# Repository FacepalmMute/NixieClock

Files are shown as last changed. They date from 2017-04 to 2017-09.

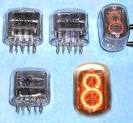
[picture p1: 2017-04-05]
doc/pic/ИН-12А-Picture.jpg

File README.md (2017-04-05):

# NixieClock
Combining Nixie tube technology with IoT
* Providing vintage style Nixie tube clock suitability for daily use.
* Building of a basis for testing and demonstrating IoT stuff using
  the [ESP8266](
  http://www.google.de/search?hl=de&source=hp&biw=&bih=&q=Mikrocontroller.net+ESP8266
  "Mikrocontroller.net ESP8266 - Google-Suche") in conjunction with
  the Arduino library.
* Open documentation allows designing of individual boxes, using of
  miscellaneous Nixie tubes, software and so forth within your own
  handicraft work.
  
# Firmware
The _firmware_ can be found in the Arduino folder. Compilation was
tested under Arduino.cc. You might use the libraries found in the
library folder. At least you will need the _NixieClock_
software. _DS1307RTC, Time-master_, and _Timezone-master_ are
available in their unimproved versions from Arduino and are assumed to
be yet part of your Arduino standard software installation. When using
the Arduino build system you can use any version you like without
problems.

When using Arduino Eclipse plugins you will get into trouble caused by
the redirection of the standard c-header file _Time.h_ that was done
in _Time-master._ This strange hijacking of the original _time.h_ is
responsible for wrecking the build process of the ESP8266 core
_arduino.ar._ So Eclipse users will likely use my modified versions of
_DS1307RTC, Time-master_, and _Timezone-master_ where I removed the
annoying redirection and detaching of standard headers.

Furthermore there are the two Arduino sketch folders _Nixie4_ and
_Nixie6._ _Nixie4_ is the firmware used by our 4 tube prototype;
_Nixie6_ is used by our 6 tube prototype.

## Prototype with 4 ИН-1 Nixie tubes
![Prototype ИН-1 Nixie clock](./pic/P1010273_s.jpg "4x ИН-1 tube
type")

This clock is an implementation with 4 ИН-1 Nixie tubes. 

## Prototype with 6 ИН-12А Nixie tubes
![Prototype ИН-12А Nixie clock](./pic/P1010278_s.jpg "6x ИН-12А tube
type")

# Hardware Description
![Beware of electric shock!](./pic/High_Voltage.jpg "Beware of
electric shock!")

**Beware of electric shock!**

**Beware of electrical safety hazards!**

**The Nixie tubes are fired at approx 200 Volt! There is definitely a
danger of hazardous voltage given! Never think of working on the Nixie
hardware when you are not educated in doing work with hazardous
voltages!**

The hardware description is given in EAGLE format and a PDF-file.

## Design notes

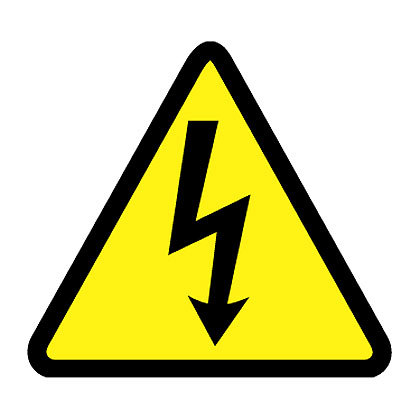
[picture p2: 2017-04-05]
pic/High_Voltage.jpg

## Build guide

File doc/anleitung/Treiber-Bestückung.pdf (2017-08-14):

## Nixie-Clock Treiber Bestückung

Die Treiberplatine liegt als EAGLE-file auf https://github.com/42nibbles/NixieClock/ vor. Sie wurde in EAGLE 7.0 erstellt und kann auch mit der freien Version geladen werden.
Diese Datei kann zu einem Platinenfertiger gesendet werden.
Wenn man sie selbst herstellen möchte, können die EAGLE-Files als PDF ausgedruckt und so für Herstellung der Filme eingesetzt werden.
Die Platine ist zweiseitig durchkontaktiert, bei selbst geätzten Platinen ist auf die korrekte Durchkontaktierung insbesondere an den IC-Sockeln zu achten. Für alle ICs sind Sockel einzusetzen, auf die korrekte Polung ist zu achten.
Der Programmierport JP1 ist als Buchse zu bestücken, der Stecker für die Erweiterung JP5 kann weggelassen werden.

Inbetriebnahme der Treiberplatine
Für die Inbetriebnahme der Treiberplatine empfiehlt es sich, zunächst die ICs für die Spannungsversorgung zu bestücken. Angefangen mit den 5V (LM2574) sollten die IC-Anschlüsse auf Spannung mit dem Multimeter überprüft werden.
Wenn die 5V-Spannung korrekt anliegt, wird der ESP8266-07 mit 3,3V versorgt, auch das sollte nachgemessen werden.
Die Hochspannung kann nicht direkt in Betrieb genommen werden, da sie über den MOSFET T10.1 (IRF9530) erst eingeschaltet wird.
An dem Stecker SV1 Pin 10 liegt die Hochspannung an erst an, wenn Source- und Drain-Anschluss von T10.1 miteinander verbunden werden.
Vorsicht, nicht mit dem HV-Schalter IRFB812P verwechseln!
VORSICHT!!!
Mit dem Voltmeter wird zwischen Masse und Pin10 des SV1 gemessen und die Spannung mit dem Potentiometer auf ca. 180V eingestellt.
Das sollte für nahezu alle Röhrentypen reichen.
Wenn die Röhren zu hell sind, kann über die Verringerung der Hochspannung die Leuchtstärke variiert werden.
Sind alle Spannungen korrekt eingestellt, können die Portextender-ICs, die RTC und die Treiber eingesetzt werden.
Für die Verbindung zwischen der Treiberplatine und der Anzeigeplatine sind Stecker und Buchsen vorgesehen.
Hier muss darauf geachtet werden, dass die Steckverbinder zueinander passen und die Pinbelegung stimmt, d.h jeweils PIN 1 auf PIN 1.
Durch verschiedene Kombinationen kann es hier zu Verdrehungen kommen, dann funktioniert nichts mehr!!!

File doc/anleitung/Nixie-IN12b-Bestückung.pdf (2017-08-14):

## Nixie-Clock IN12b Platinen-Bestückung

Auch hier liegen die EAGLE-Files auf https://github.com/42nibbles/NixieClock/.
Die Platine ist zweiseitig durchkontaktiert, allerdings sind hier keine Durchkontaktierungen an den Steckern und Röhren vorgesehen, lediglich an den Widerständen muss oben und unten gelötet werden.
Außerdem sind die Durchkontaktierungen vor den Steckern sorgfältig zu löten.

Die Röhren müssen in den Bohrungen vorsichtig justiert werden, da sie handgefertigt sind, sind die Ziffern der einzelnen Röhren nicht sauber justiert. Hier muss nach Sicht ausgeglichen werden. Die Röhren sollten dann mit Klebeband fixiert und angelötet werden.

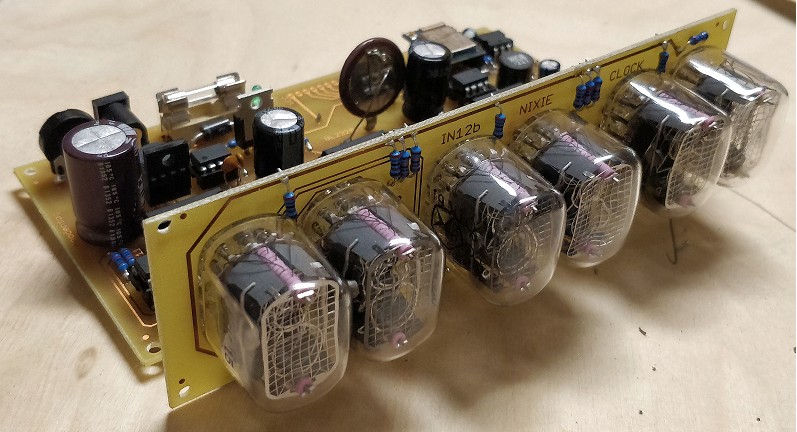
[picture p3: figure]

Quelle: Vincent Tummel

Wenn die Steckverbinder der Treiber- und der Röhrenplatine verlötet werden sollen, ist es ratsam, auch die beiden Platinen erst auszurichten (Rechter Winkel!) und zu fixieren und dann anzulöten.

Jetzt kann die Uhr, bzw der ESP8266 programmiert und die Uhr in Betrieb genommen werden.

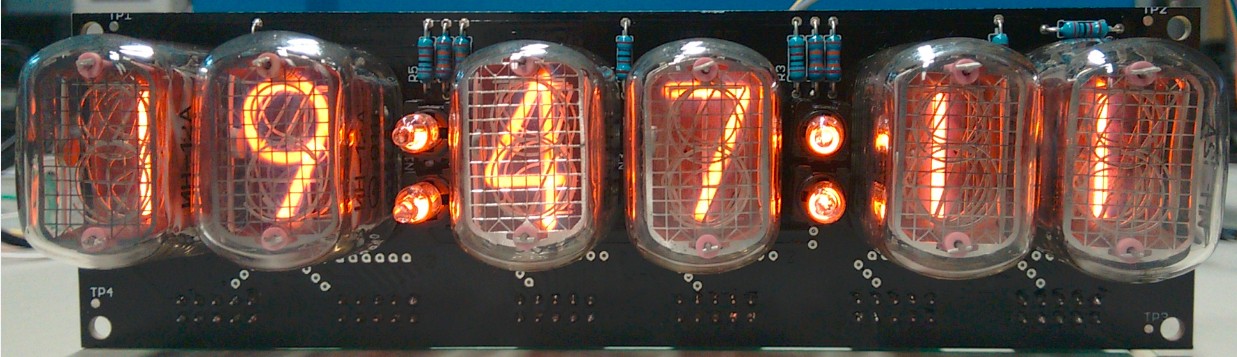
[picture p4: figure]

Quelle: Daniel Flaswinkel

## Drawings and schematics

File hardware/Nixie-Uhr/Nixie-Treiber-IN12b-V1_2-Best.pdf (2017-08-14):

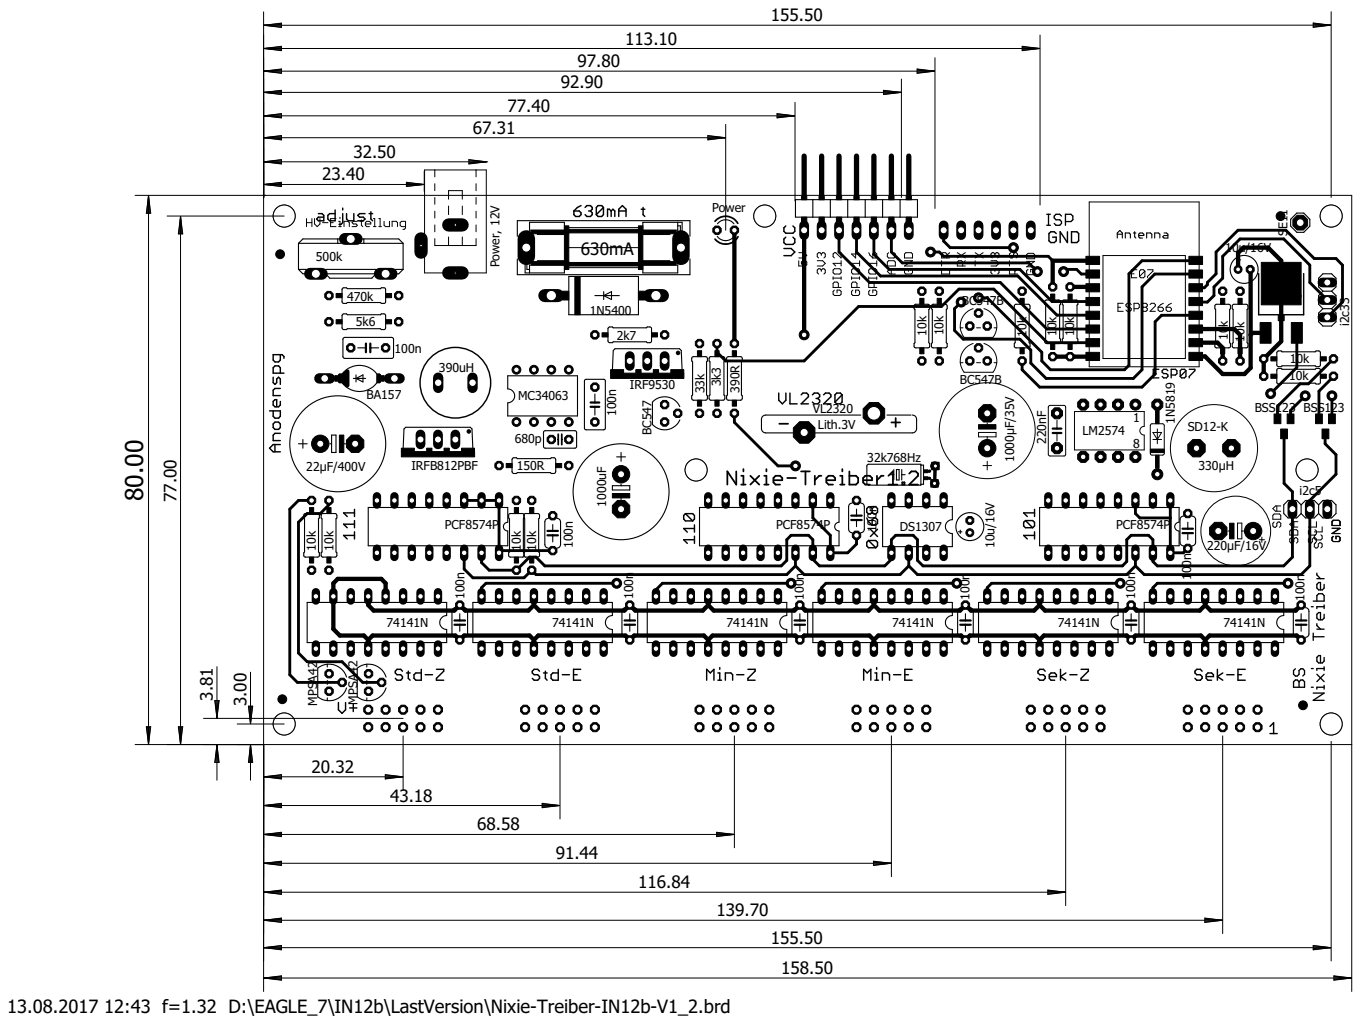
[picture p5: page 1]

13.08.2017 12:43 f=1.32 D:\EAGLE_7\IN12b\LastVersion\Nixie-Treiber-IN12b-V1_2.brd

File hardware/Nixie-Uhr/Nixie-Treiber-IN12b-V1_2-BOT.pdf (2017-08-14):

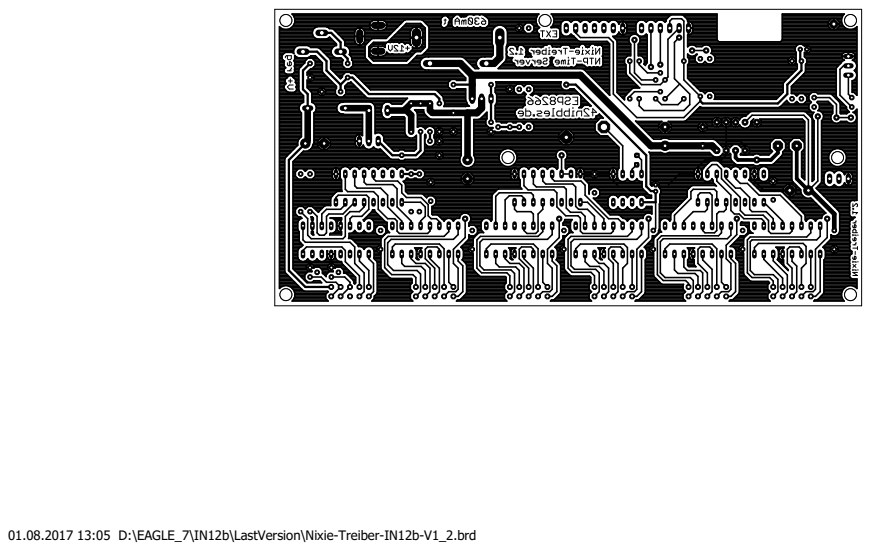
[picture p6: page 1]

01.08.2017 13:05 D:\EAGLE_7\IN12b\LastVersion\Nixie-Treiber-IN12b-V1_2.brd

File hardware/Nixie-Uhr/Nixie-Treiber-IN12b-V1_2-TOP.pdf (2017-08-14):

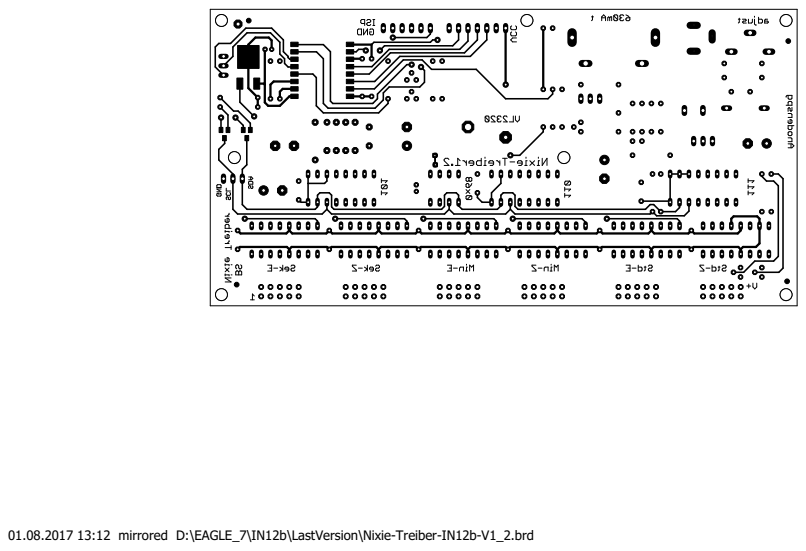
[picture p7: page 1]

01.08.2017 13:12 mirrored D:\EAGLE_7\IN12b\LastVersion\Nixie-Treiber-IN12b-V1_2.brd

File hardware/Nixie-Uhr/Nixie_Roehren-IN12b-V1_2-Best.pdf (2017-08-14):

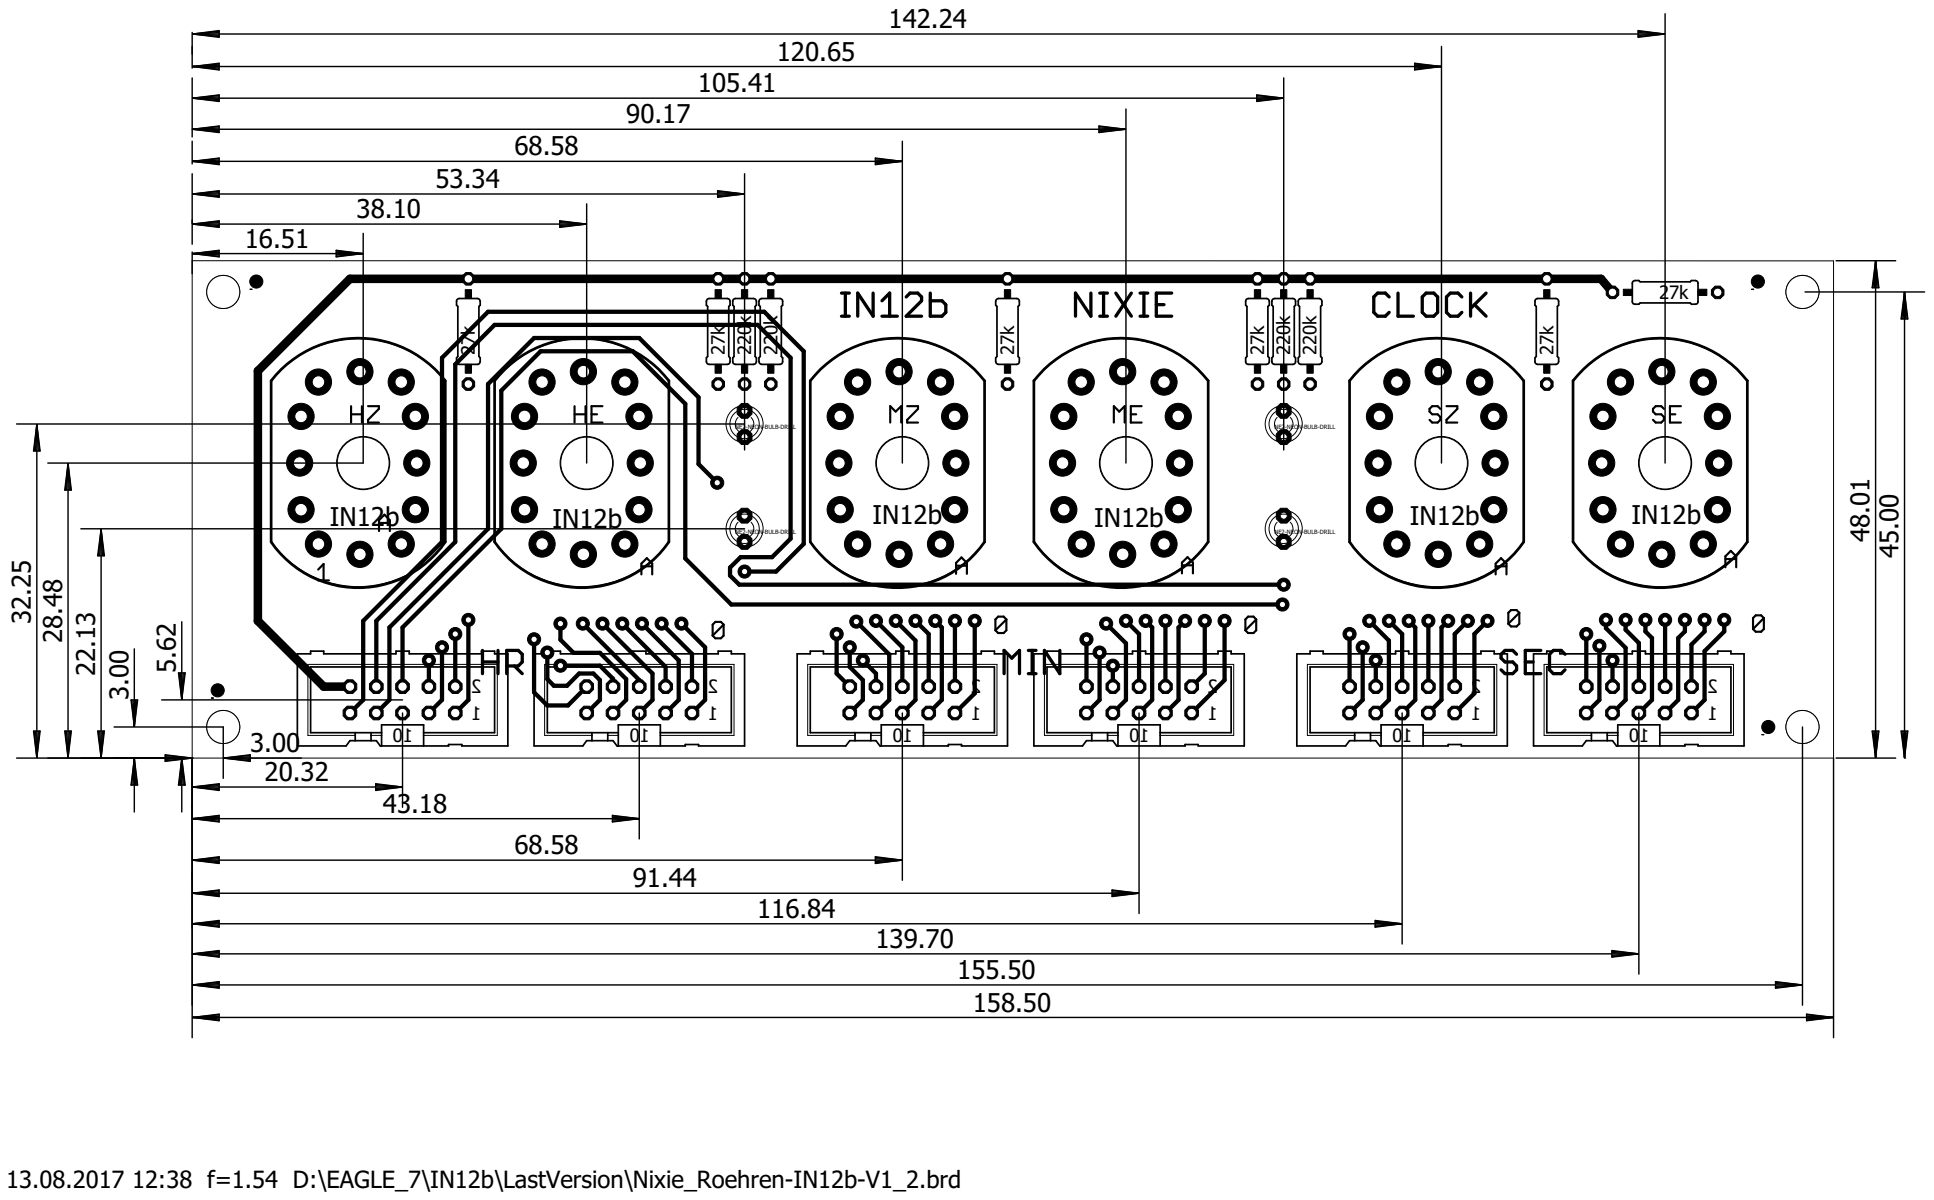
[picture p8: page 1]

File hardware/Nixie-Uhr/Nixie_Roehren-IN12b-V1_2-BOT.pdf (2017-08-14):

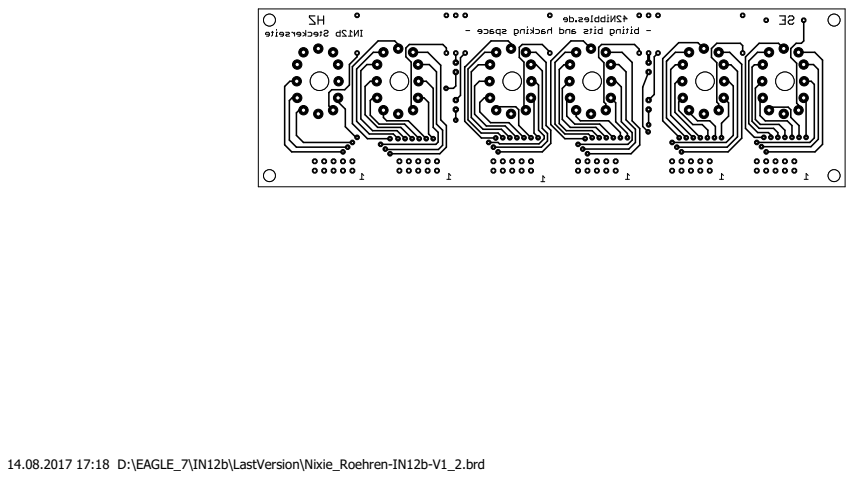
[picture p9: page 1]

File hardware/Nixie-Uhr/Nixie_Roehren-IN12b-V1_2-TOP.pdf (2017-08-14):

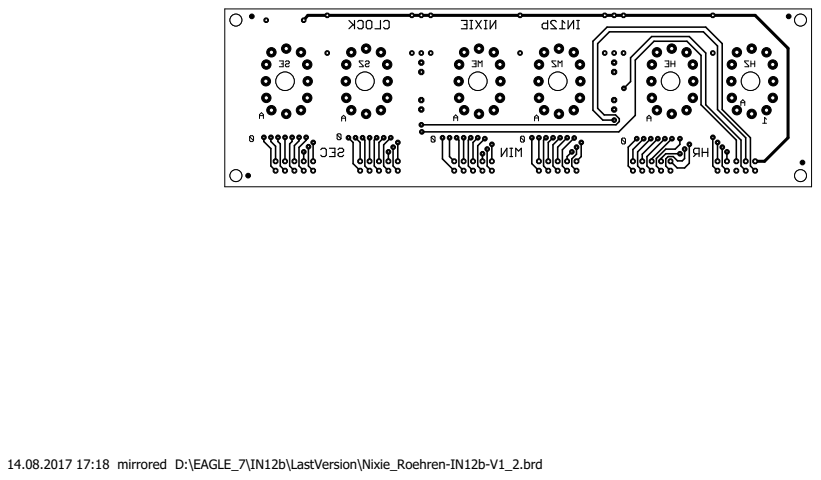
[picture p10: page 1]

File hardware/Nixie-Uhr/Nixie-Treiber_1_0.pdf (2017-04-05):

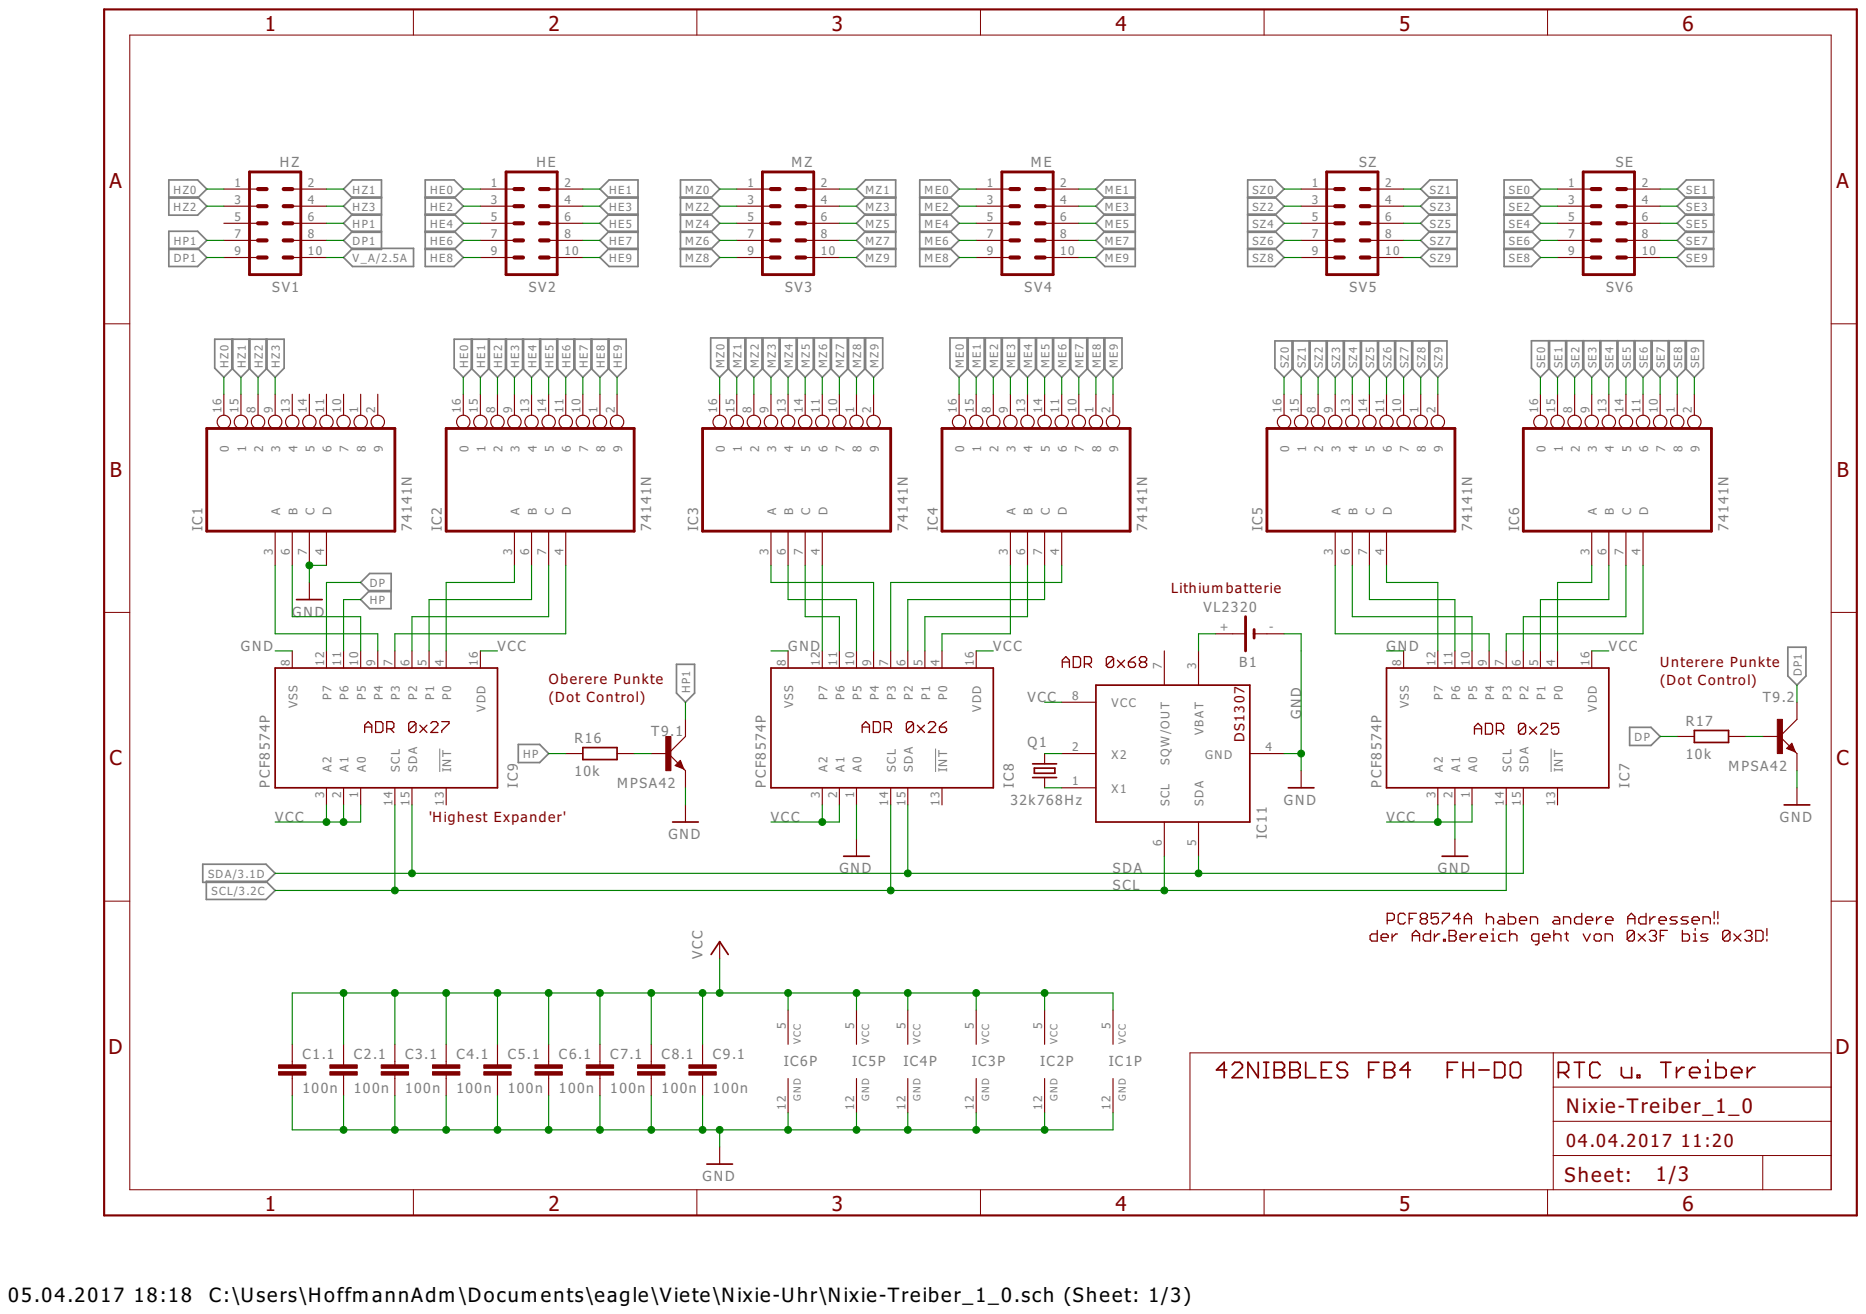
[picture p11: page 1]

05.04.2017 18:18 C:\Users\HoffmannAdm\Documents\eagle\Viete\Nixie-Uhr\Nixie-Treiber_1_0.sch (Sheet: 1/3)

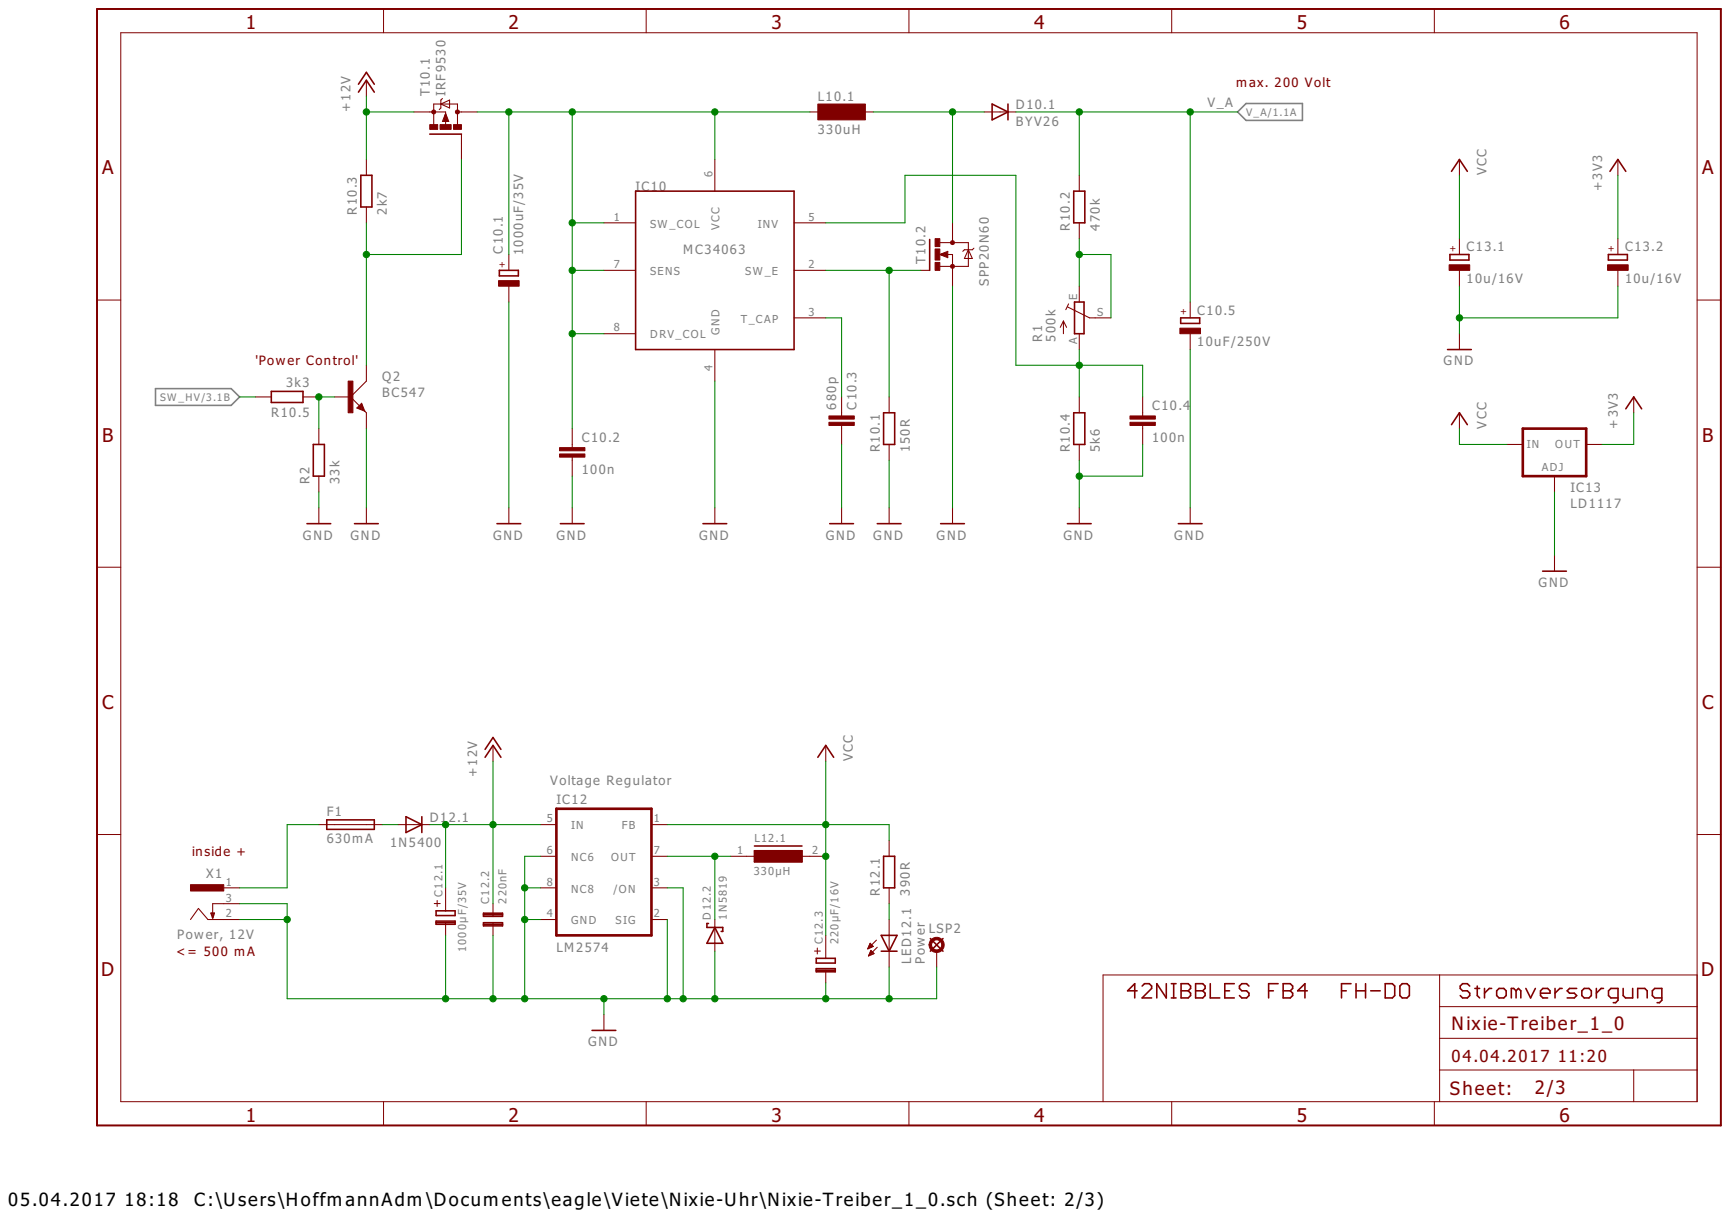
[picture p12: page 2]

05.04.2017 18:18 C:\Users\HoffmannAdm\Documents\eagle\Viete\Nixie-Uhr\Nixie-Treiber_1_0.sch (Sheet: 2/3)

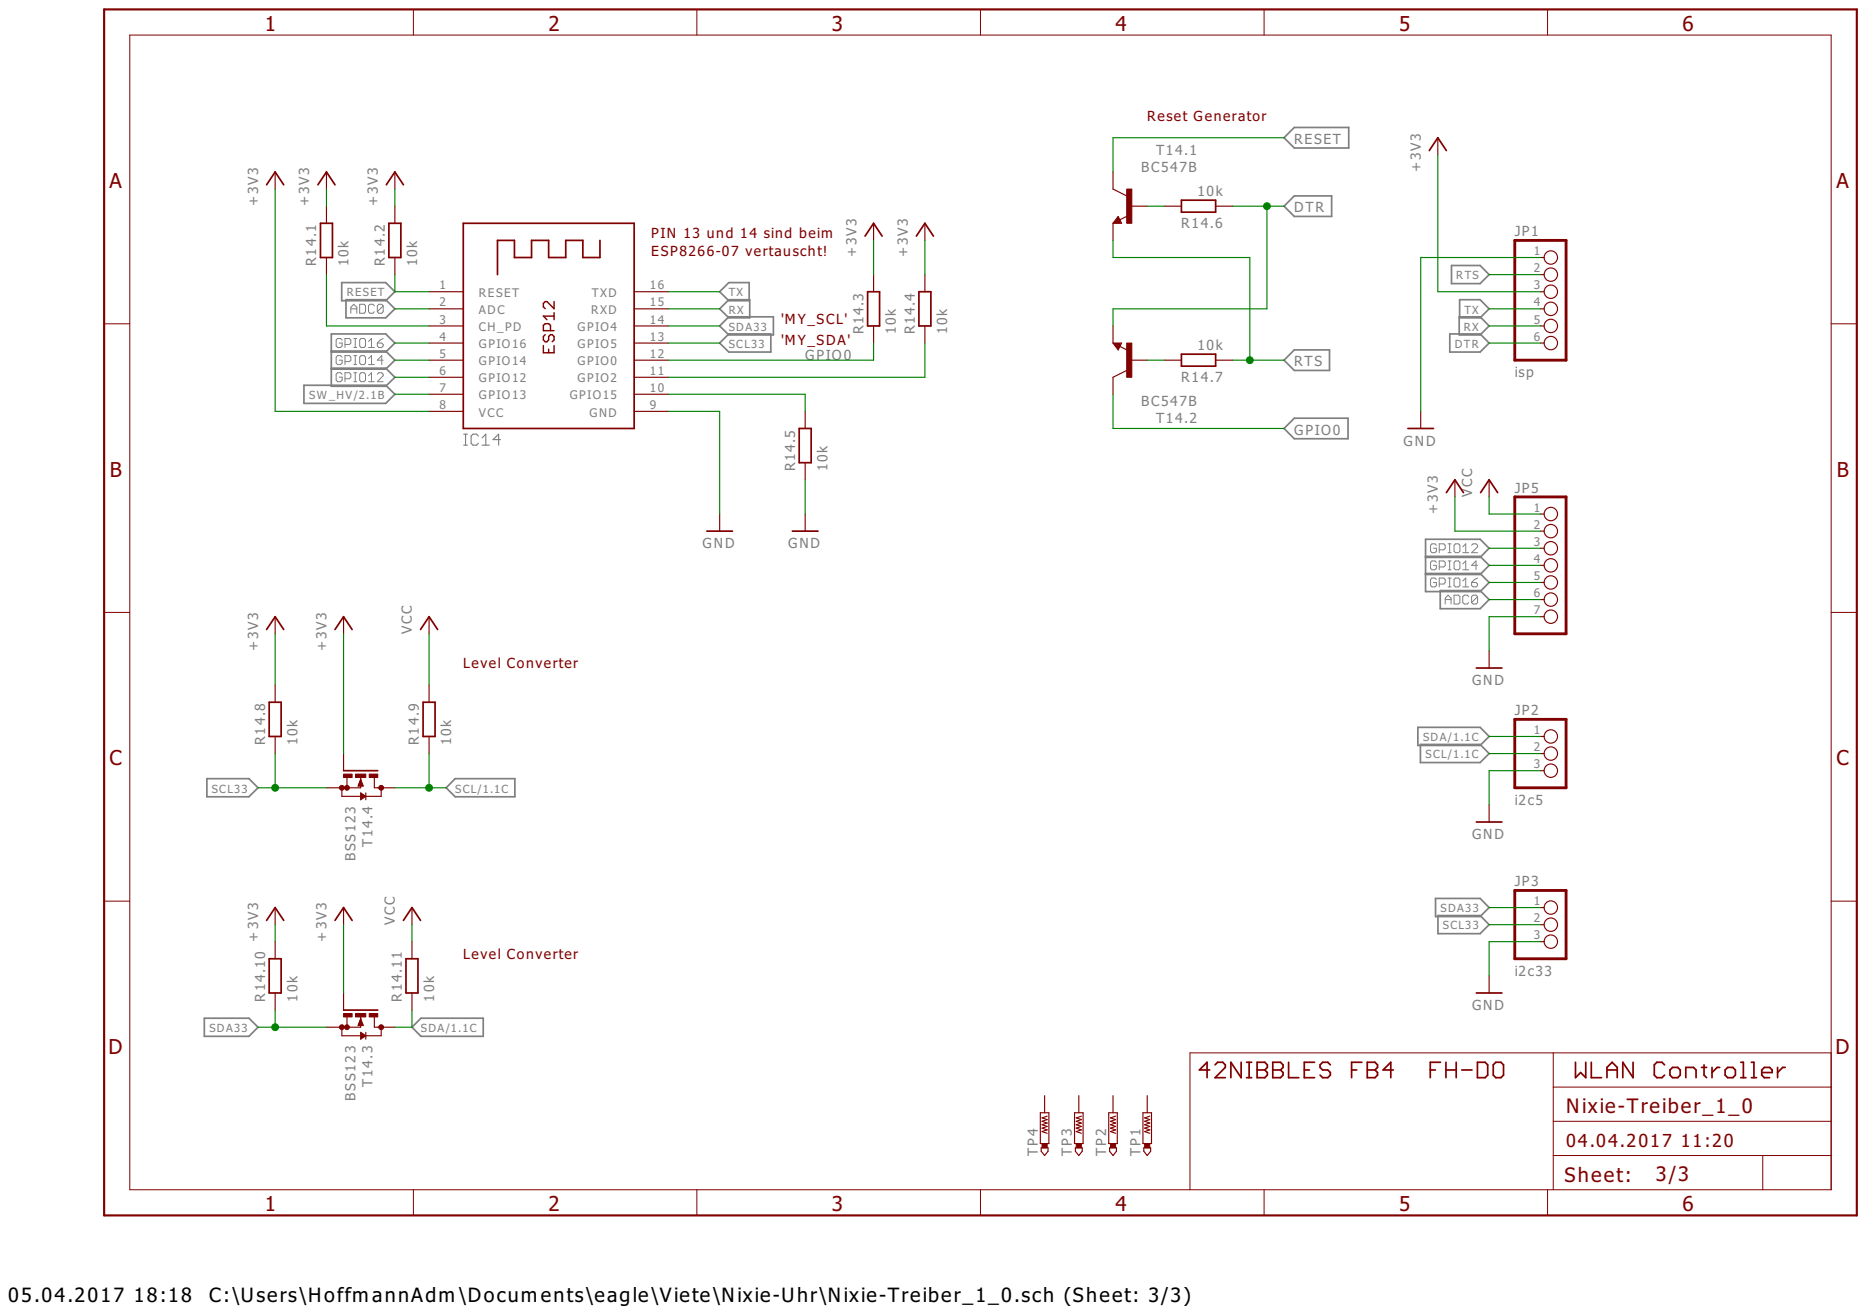
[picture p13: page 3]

PIN 13 und 14 sind beim
ESP8266-07 vertauscht!

05.04.2017 18:18 C:\Users\HoffmannAdm\Documents\eagle\Viete\Nixie-Uhr\Nixie-Treiber_1_0.sch (Sheet: 3/3)

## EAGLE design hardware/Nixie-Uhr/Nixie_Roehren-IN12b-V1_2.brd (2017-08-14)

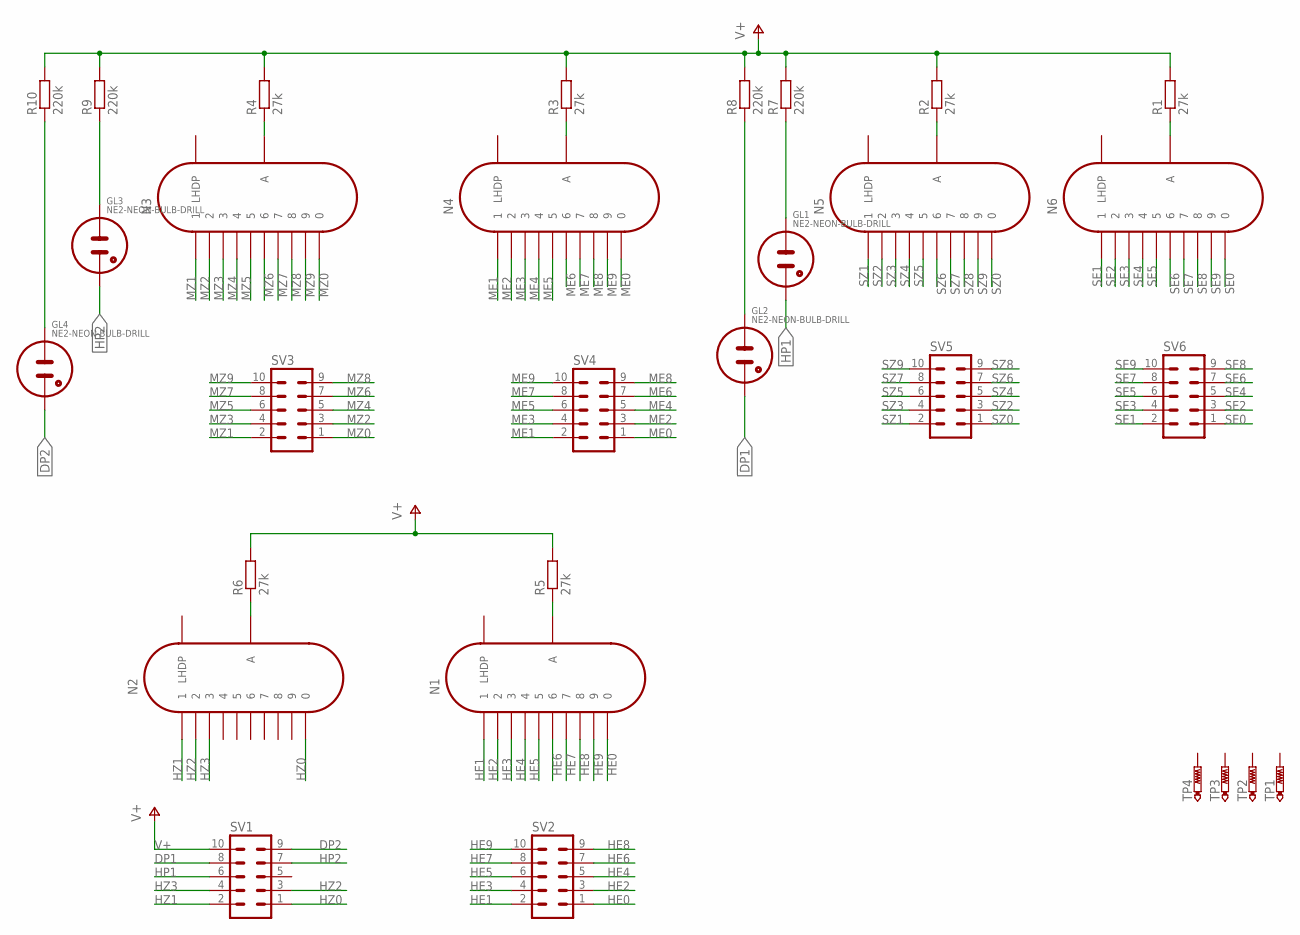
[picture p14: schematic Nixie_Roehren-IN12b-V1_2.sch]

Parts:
GL1, GL2, GL3, GL4: NE2-NEON-BULB-DRILL
N1, N2, N3, N4, N5, N6: IN-12B; IN-12
R1, R2, R3, R4, R5, R6: 27k; 0207/10
R7, R8, R9, R10: 220k; 0207/10
SV1, SV2, SV3, SV4, SV5, SV6: ML10
TP1, TP2, TP3, TP4: PTR1B1,27; B1,27

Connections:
DP1: GL2.2 (A1), SV1.8
DP2: GL4.2 (A1), SV1.9
HE0: N1.0, SV2.1
HE1: N1.1, SV2.2
HE2: N1.2, SV2.3
HE3: N1.3, SV2.4
HE4: N1.4, SV2.5
HE5: N1.5, SV2.6
HE6: N1.6, SV2.7
HE7: N1.7, SV2.8
HE8: N1.8, SV2.9
HE9: N1.9, SV2.10
HP1: GL1.2 (A1), SV1.6
HP2: GL3.2 (A1), SV1.7
HZ0: N2.0, SV1.1
HZ1: N2.1, SV1.2
HZ2: N2.2, SV1.3
HZ3: N2.3, SV1.4
ME0: N4.0, SV4.1
ME1: N4.1, SV4.2
ME2: N4.2, SV4.3
ME3: N4.3, SV4.4
ME4: N4.4, SV4.5
ME5: N4.5, SV4.6
ME6: N4.6, SV4.7
ME7: N4.7, SV4.8
ME8: N4.8, SV4.9
ME9: N4.9, SV4.10
MZ0: N3.0, SV3.1
MZ1: N3.1, SV3.2
MZ2: N3.2, SV3.3
MZ3: N3.3, SV3.4
MZ4: N3.4, SV3.5
MZ5: N3.5, SV3.6
MZ6: N3.6, SV3.7
MZ7: N3.7, SV3.8
MZ8: N3.8, SV3.9
MZ9: N3.9, SV3.10
unnamed: N2.A, R6.1
unnamed: N6.A, R1.1
unnamed: N5.A, R2.1
unnamed: N4.A, R3.1
unnamed: N3.A, R4.1
unnamed: GL2.1 (A), R8.1
unnamed: N1.A, R5.1
unnamed: GL1.1 (A), R7.1
unnamed: GL4.1 (A), R10.1
unnamed: GL3.1 (A), R9.1
SE0: N6.0, SV6.1
SE1: N6.1, SV6.2
SE2: N6.2, SV6.3
SE3: N6.3, SV6.4
SE4: N6.4, SV6.5
SE5: N6.5, SV6.6
SE6: N6.6, SV6.7
SE7: N6.7, SV6.8
SE8: N6.8, SV6.9
SE9: N6.9, SV6.10
SZ0: N5.0, SV5.1
SZ1: N5.1, SV5.2
SZ2: N5.2, SV5.3
SZ3: N5.3, SV5.4
SZ4: N5.4, SV5.5
SZ5: N5.5, SV5.6
SZ6: N5.6, SV5.7
SZ7: N5.7, SV5.8
SZ8: N5.8, SV5.9
SZ9: N5.9, SV5.10
V+: R1.2, R2.2, R3.2, R4.2, R5.2, R6.2, R7.2, R8.2, R9.2, R10.2, SV1.10

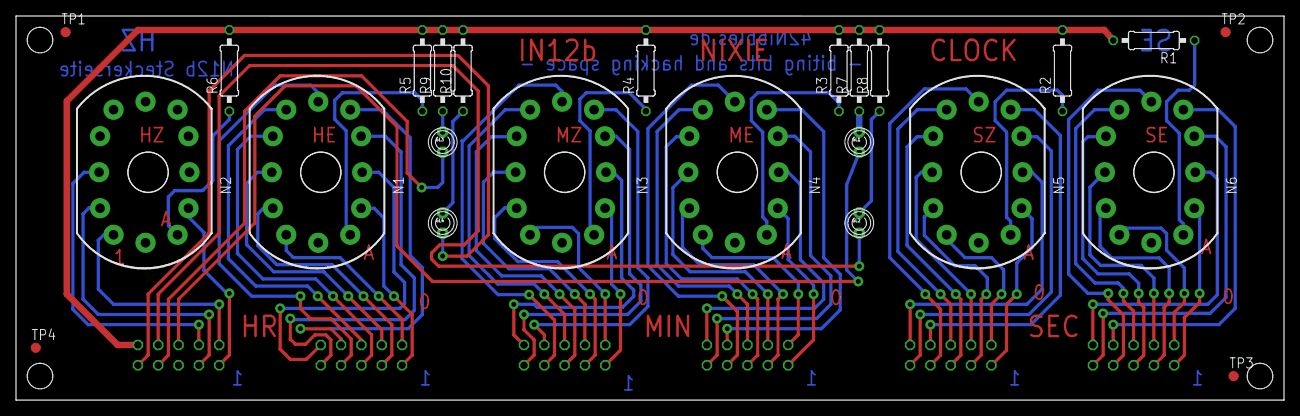
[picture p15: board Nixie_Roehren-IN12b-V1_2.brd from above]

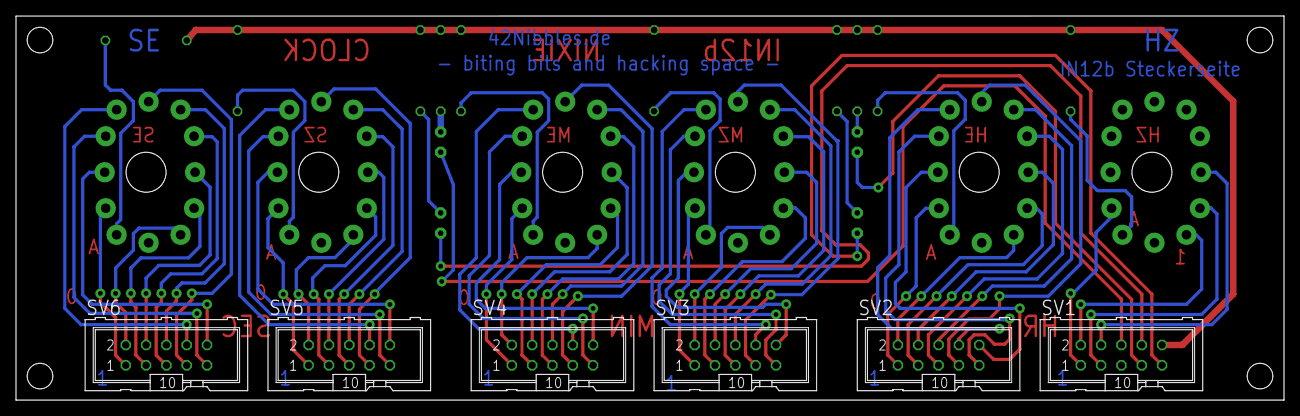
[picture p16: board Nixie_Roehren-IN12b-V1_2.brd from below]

Board: 2 copper layers, 158.5 x 48.0 mm, 30 parts (6 on the bottom side), 69 nets.

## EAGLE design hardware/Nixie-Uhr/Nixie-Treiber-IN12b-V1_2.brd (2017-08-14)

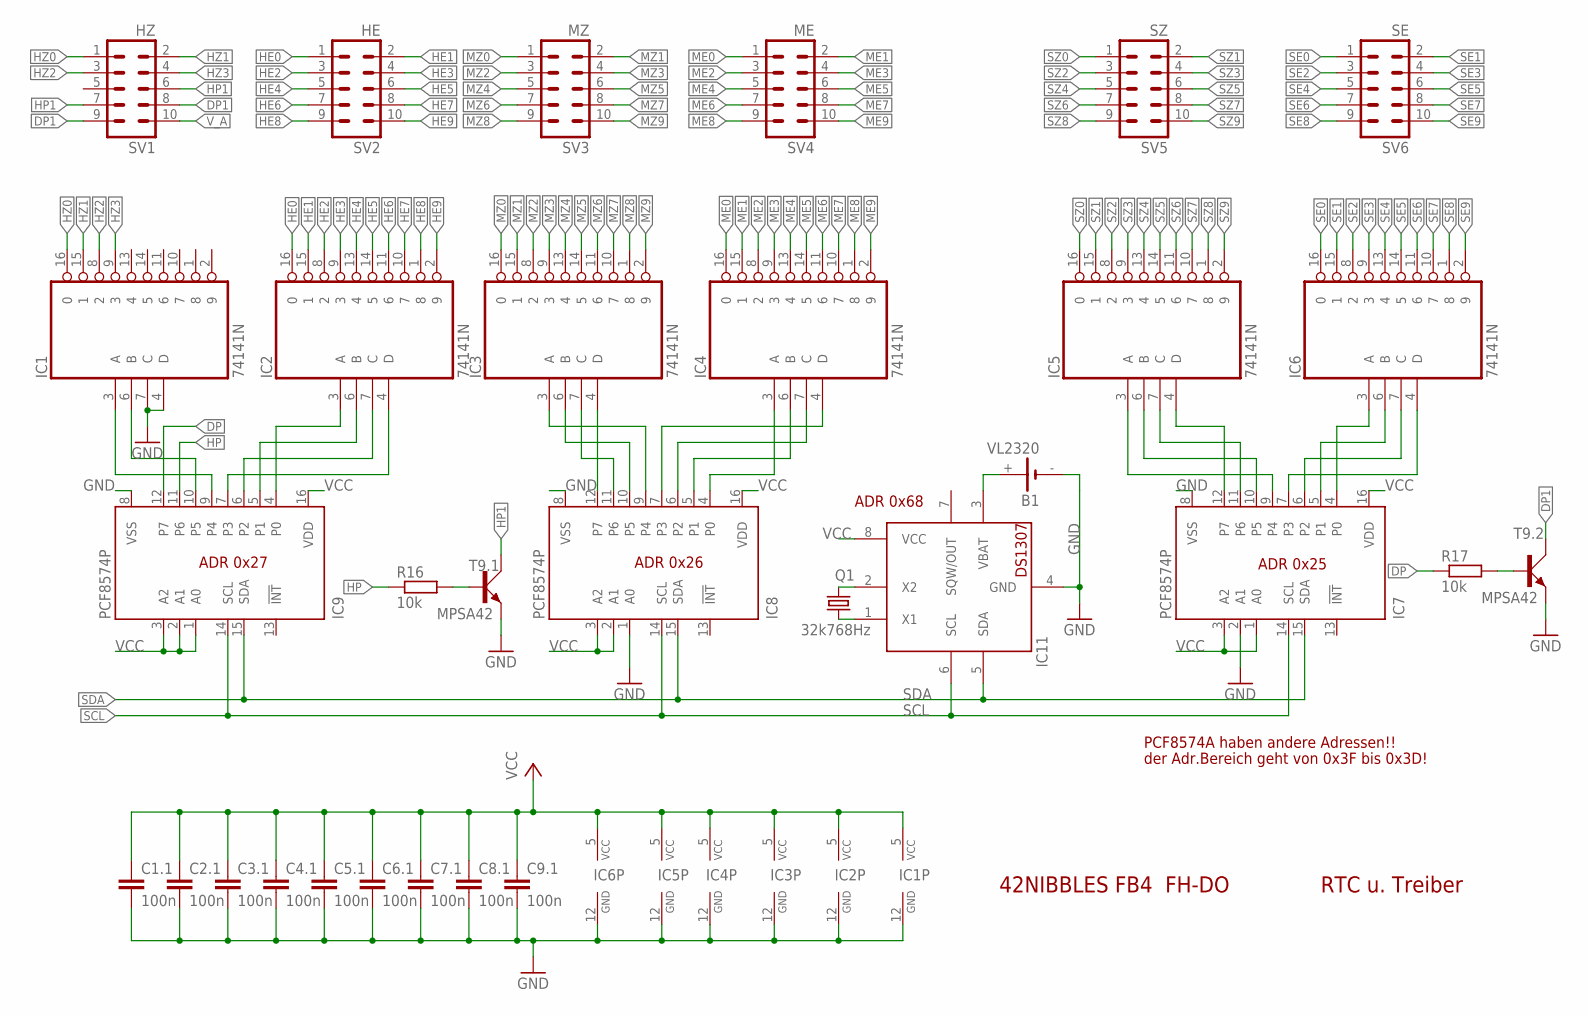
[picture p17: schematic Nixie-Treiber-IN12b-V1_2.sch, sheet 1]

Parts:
B1: VL2320
C1.1, C2.1, C3.1, C4.1, C5.1, C6.1, C7.1, C8.1, C9.1: 100n; C050-024X044
IC1, IC2, IC3, IC4, IC5, IC6: 74141N; DIL16
IC7, IC8, IC9: PCF8574P; DIL16
IC11: DS1307; DIL08
Q1: 32k768Hz; TC38H
R16, R17: 10k; 0207/10
SV1: HZ; ML10
SV2: HE; ML10
SV3: MZ; ML10
SV4: ME; ML10
SV5: SZ; ML10
SV6: SE; ML10
T9.1, T9.2: MPSA42; TO92D

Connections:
DP: IC9.12 (P7), R17.1
DP1: SV1.8, SV1.9, T9.2.C
GND: B1.-, C1.1.2, C2.1.2, C3.1.2, C4.1.2, C5.1.2, C6.1.2, C7.1.2, C8.1.2, C9.1.2, IC1.4 (D), IC1.7 (C), IC1.12 (GND), IC2.12 (GND), IC3.12 (GND), IC4.12 (GND), IC5.12 (GND), IC6.12 (GND), IC7.2 (A1), IC7.8 (VSS), IC8.1 (A0), IC8.8 (VSS), IC9.8 (VSS), IC11.4 (GND), T9.1.E, T9.2.E; also elsewhere on the board
HE0: IC2.16 (0), SV2.1
HE1: IC2.15 (1), SV2.2
HE2: IC2.8 (2), SV2.3
HE3: IC2.9 (3), SV2.4
HE4: IC2.13 (4), SV2.5
HE5: IC2.14 (5), SV2.6
HE6: IC2.11 (6), SV2.7
HE7: IC2.10 (7), SV2.8
HE8: IC2.1 (8), SV2.9
HE9: IC2.2 (9), SV2.10
HP: IC9.11 (P6), R16.1
HP1: SV1.6, SV1.7, T9.1.C
HZ0: IC1.16 (0), SV1.1
HZ1: IC1.15 (1), SV1.2
HZ2: IC1.8 (2), SV1.3
HZ3: IC1.9 (3), SV1.4
ME0: IC4.16 (0), SV4.1
ME1: IC4.15 (1), SV4.2
ME2: IC4.8 (2), SV4.3
ME3: IC4.9 (3), SV4.4
ME4: IC4.13 (4), SV4.5
ME5: IC4.14 (5), SV4.6
ME6: IC4.11 (6), SV4.7
ME7: IC4.10 (7), SV4.8
ME8: IC4.1 (8), SV4.9
ME9: IC4.2 (9), SV4.10
MZ0: IC3.16 (0), SV3.1
MZ1: IC3.15 (1), SV3.2
MZ2: IC3.8 (2), SV3.3
MZ3: IC3.9 (3), SV3.4
MZ4: IC3.13 (4), SV3.5
MZ5: IC3.14 (5), SV3.6
MZ6: IC3.11 (6), SV3.7
MZ7: IC3.10 (7), SV3.8
MZ8: IC3.1 (8), SV3.9
MZ9: IC3.2 (9), SV3.10
unnamed: IC2.3 (A), IC9.4 (P0)
unnamed: IC2.6 (B), IC9.5 (P1)
unnamed: IC2.7 (C), IC9.6 (P2)
unnamed: IC2.4 (D), IC9.7 (P3)
unnamed: IC1.3 (A), IC9.9 (P4)
unnamed: IC1.6 (B), IC9.10 (P5)
unnamed: R16.2, T9.1.B
unnamed: R17.2, T9.2.B
unnamed: IC4.3 (A), IC8.4 (P0)
unnamed: IC4.6 (B), IC8.5 (P1)
unnamed: IC4.7 (C), IC8.6 (P2)
unnamed: IC4.4 (D), IC8.7 (P3)
unnamed: IC3.3 (A), IC8.9 (P4)
unnamed: IC3.6 (B), IC8.10 (P5)
unnamed: IC3.7 (C), IC8.11 (P6)
unnamed: IC3.4 (D), IC8.12 (P7)
unnamed: IC6.3 (A), IC7.4 (P0)
unnamed: IC6.6 (B), IC7.5 (P1)
unnamed: IC6.7 (C), IC7.6 (P2)
unnamed: IC6.4 (D), IC7.7 (P3)
unnamed: IC5.3 (A), IC7.9 (P4)
unnamed: IC5.6 (B), IC7.10 (P5)
unnamed: IC5.7 (C), IC7.11 (P6)
unnamed: IC5.4 (D), IC7.12 (P7)
unnamed: IC11.2 (X2), Q1.2
unnamed: IC11.1 (X1), Q1.1
unnamed: B1.+, IC11.3 (VBAT)
SCL: IC7.14 (SCL), IC8.14 (SCL), IC9.14 (SCL), IC11.6 (SCL); also elsewhere on the board
SDA: IC7.15 (SDA), IC8.15 (SDA), IC9.15 (SDA), IC11.5 (SDA); also elsewhere on the board
SE0: IC6.16 (0), SV6.1
SE1: IC6.15 (1), SV6.2
SE2: IC6.8 (2), SV6.3
SE3: IC6.9 (3), SV6.4
SE4: IC6.13 (4), SV6.5
SE5: IC6.14 (5), SV6.6
SE6: IC6.11 (6), SV6.7
SE7: IC6.10 (7), SV6.8
SE8: IC6.1 (8), SV6.9
SE9: IC6.2 (9), SV6.10
SZ0: IC5.16 (0), SV5.1
SZ1: IC5.15 (1), SV5.2
SZ2: IC5.8 (2), SV5.3
SZ3: IC5.9 (3), SV5.4
SZ4: IC5.13 (4), SV5.5
SZ5: IC5.14 (5), SV5.6
SZ6: IC5.11 (6), SV5.7
SZ7: IC5.10 (7), SV5.8
SZ8: IC5.1 (8), SV5.9
SZ9: IC5.2 (9), SV5.10
VCC: C1.1.1, C2.1.1, C3.1.1, C4.1.1, C5.1.1, C6.1.1, C7.1.1, C8.1.1, C9.1.1, IC1.5 (VCC), IC2.5 (VCC), IC3.5 (VCC), IC4.5 (VCC), IC5.5 (VCC), IC6.5 (VCC), IC7.1 (A0), IC7.3 (A2), IC7.16 (VDD), IC8.2 (A1), IC8.3 (A2), IC8.16 (VDD), IC9.1 (A0), IC9.2 (A1), IC9.3 (A2), IC9.16 (VDD), IC11.8 (VCC); also elsewhere on the board
V_A: SV1.10; also elsewhere on the board

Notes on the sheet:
42NIBBLES FB4 FH-DO
RTC u. Treiber
ADR 0x27
ADR 0x26
ADR 0x25
ADR 0x68
PCF8574A haben andere Adressen!!
der Adr.Bereich geht von 0x3F bis 0x3D!

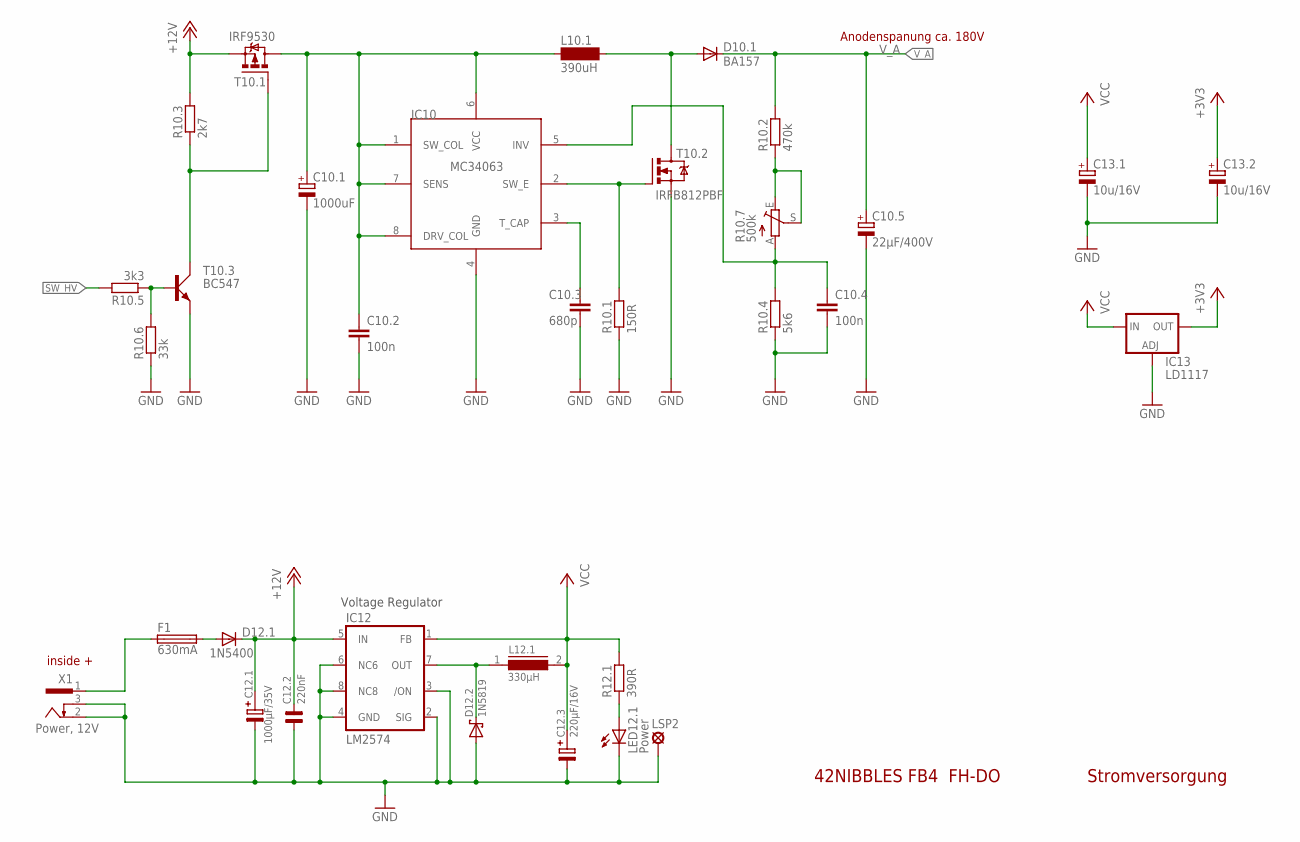
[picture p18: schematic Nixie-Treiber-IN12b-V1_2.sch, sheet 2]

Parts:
C10.1: 1000uF; E5-13
C10.2, C10.4: 100n; C050-030X075
C10.3: 680p; C025-025X050
C10.5: 22µF/400V; E5-13
C12.1: 1000µF/35V; E5-13
C12.2: 220nF; C5B2,5
C12.3: 220µF/16V; E5-10,5
C13.1, C13.2: 10u/16V; E1,8-4
D10.1: BA157; DO204-10
D12.1: 1N5400; DO201-15
D12.2: 1N5819; DO35-10
F1: 630mA; SH22,5
IC10: MC34063; DIL08
IC12: LM2574
IC13: LD1117; DPACK
L10.1: 390uH; SD12K100
L12.1: 330µH; SD12-K
LED12.1: Power; LED3MM
LSP2: SE11
R10.1: 150R; 0207/10
R10.2: 470k; 0207/10
R10.3: 2k7; 0207/10
R10.4: 5k6; 0207/10
R10.5: 3k3; 0207/10
R10.6: 33k; 0207/10
R10.7: 500k; ST15
R12.1: 390R; 0207/10
T10.1: IRF9530; TO220BV
T10.2: IRFB812PBF; TO220BV
T10.3: BC547; SOT54A
X1: Power, 12V; HEBW21

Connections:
+3V3: C13.2.+, IC13.4 (OUT); also elsewhere on the board
+12V: C12.1.+, C12.2.2, D12.1.C, IC12.5 (IN), R10.3.2, T10.1.S
GND: C10.1.-, C10.2.2, C10.3.2, C10.4.2, C10.5.-, C12.1.-, C12.2.1, C12.3.-, C13.1.-, C13.2.-, D12.2.A, IC10.4 (GND), IC12.2 (SIG), IC12.3 (/ON), IC12.4 (GND), IC12.6 (NC6), IC12.8 (NC8), IC13.1 (ADJ), LED12.1.K (C), LSP2.MP, R10.1.1, R10.4.1, R10.6.1, T10.2.S, T10.3.E, X1.2, X1.3; also elsewhere on the board
HV_IN: C10.1.+, C10.2.1, IC10.1 (SW_COL), IC10.6 (VCC), IC10.7 (SENS), IC10.8 (DRV_COL), L10.1.1, T10.1.D
unnamed: C10.3.1, IC10.3 (T_CAP)
unnamed: IC10.2 (SW_E), R10.1.2, T10.2.G
unnamed: D10.1.A, L10.1.2, T10.2.D
unnamed: D12.2.K, IC12.7 (OUT), L12.1.1
unnamed: C10.4.1, IC10.5 (INV), R10.4.2, R10.7.A
unnamed: R10.2.1, R10.7.E, R10.7.S
unnamed: LED12.1.A, R12.1.1
unnamed: R10.3.1, T10.1.G, T10.3.C
unnamed: D12.1.A, F1.2
unnamed: R10.5.1, R10.6.2, T10.3.B
SW_HV: R10.5.2; also elsewhere on the board
VCC: C12.3.+, C13.1.+, IC12.1 (FB), IC13.3 (IN), L12.1.2, R12.1.2; also elsewhere on the board
VIN: F1.1, X1.1
V_A: C10.5.+, D10.1.C, R10.2.2; also elsewhere on the board

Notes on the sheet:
Voltage Regulator
42NIBBLES FB4 FH-DO
Stromversorgung
inside +
Anodenspanung ca. 180V

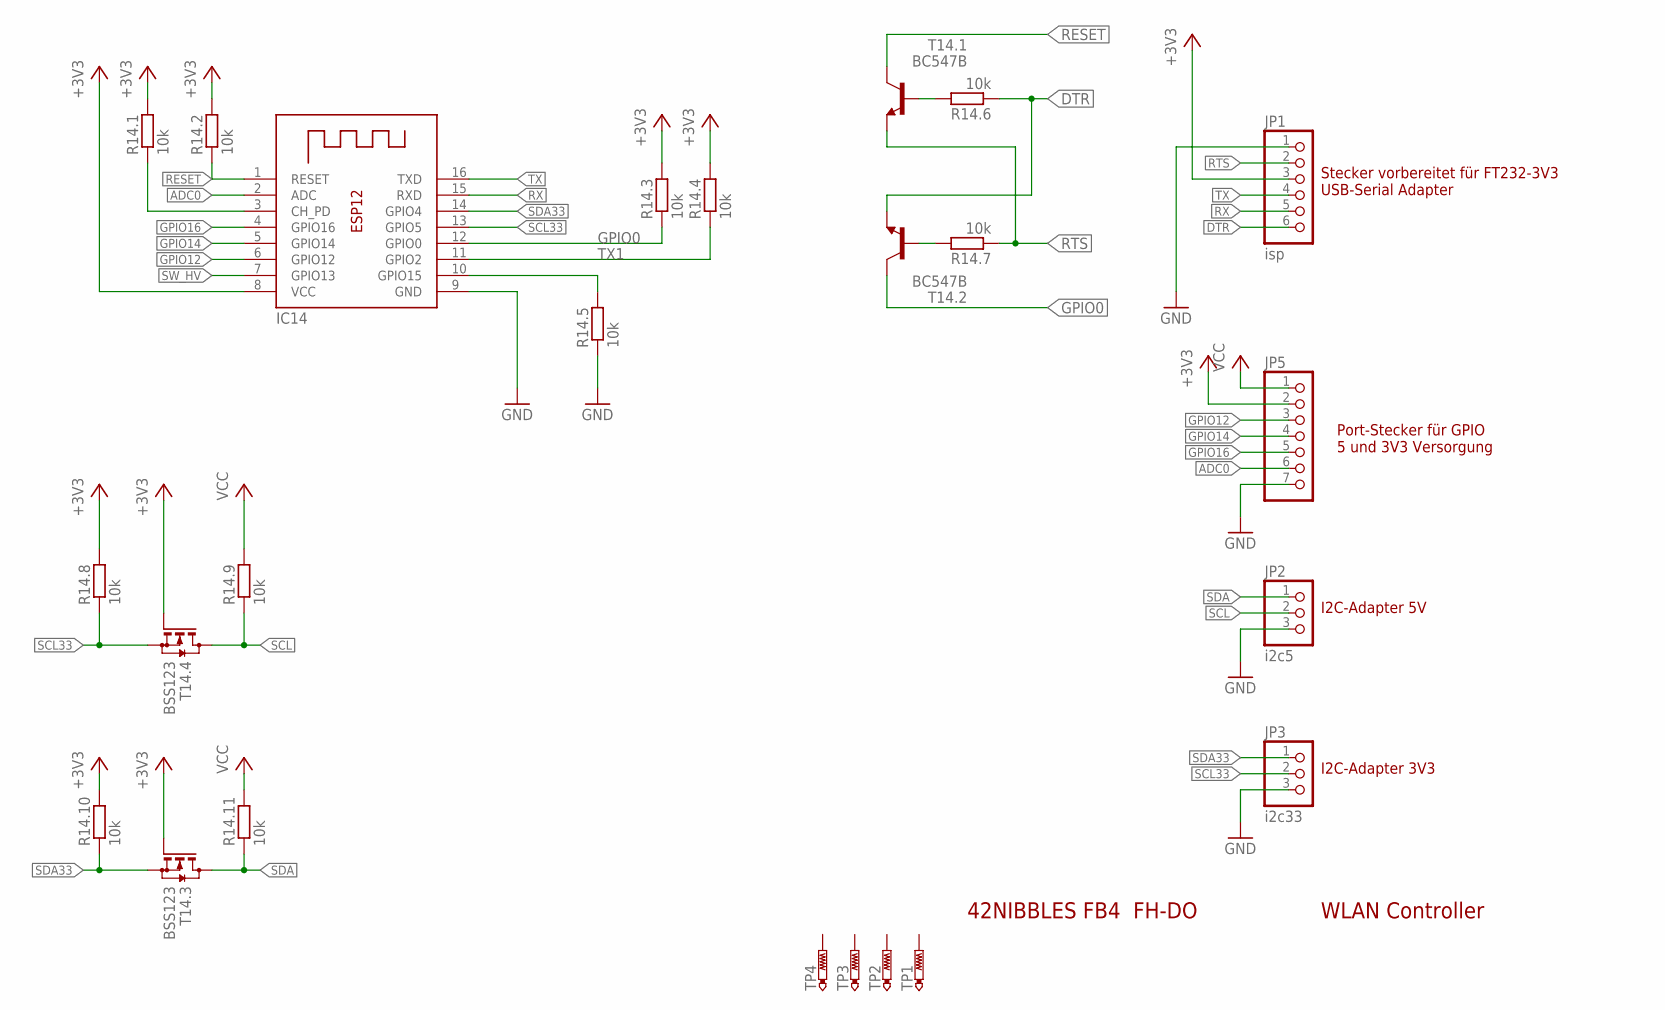
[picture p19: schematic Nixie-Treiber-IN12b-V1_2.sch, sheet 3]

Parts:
IC14: ESP07; ESP-12
JP1: isp; 1X06/90
JP2: i2c5; 1X03
JP3: i2c33; 1X03
JP5: PINHD-1X7/90; 1X07/90
R14.1, R14.2, R14.3, R14.4, R14.5, R14.6, R14.7, R14.8, R14.9, R14.10, R14.11: 10k; 0207/10
T14.1, T14.2: BC547B; TO92
T14.3, T14.4: BSS123; SOT23
TP1, TP2, TP3, TP4: PTR1B1,27; B1,27

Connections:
+3V3: IC14.8 (VCC), JP1.3, JP5.2, R14.1.2, R14.2.2, R14.3.2, R14.4.2, R14.8.2, R14.10.2, T14.3.1 (G), T14.4.1 (G); also elsewhere on the board
ADC0: IC14.2 (ADC), JP5.6
DTR: JP1.6, R14.6.1, T14.2.1 (E)
GND: IC14.9 (GND), JP1.1, JP2.3, JP3.3, JP5.7, R14.5.1; also elsewhere on the board
GPIO0: IC14.12 (GPIO0), R14.3.1, T14.2.3 (C)
GPIO12: IC14.6 (GPIO12), JP5.3
GPIO14: IC14.5 (GPIO14), JP5.4
GPIO16: IC14.4 (GPIO16), JP5.5
unnamed: IC14.10 (GPIO15), R14.5.2
unnamed: IC14.3 (CH_PD), R14.1.1
unnamed: R14.7.2, T14.2.2 (B)
unnamed: R14.6.2, T14.1.2 (B)
RESET: IC14.1 (RESET), R14.2.1, T14.1.3 (C)
RTS: JP1.2, R14.7.1, T14.1.1 (E)
RX: IC14.15 (RXD), JP1.5
SCL: JP2.2, R14.9.1, T14.4.3 (D); also elsewhere on the board
SCL33: IC14.13 (GPIO5), JP3.2, R14.8.1, T14.4.2 (S)
SDA: JP2.1, R14.11.1, T14.3.3 (D); also elsewhere on the board
SDA33: IC14.14 (GPIO4), JP3.1, R14.10.1, T14.3.2 (S)
SW_HV: IC14.7 (GPIO13); also elsewhere on the board
TX: IC14.16 (TXD), JP1.4
TX1: IC14.11 (GPIO2), R14.4.1
VCC: JP5.1, R14.9.2, R14.11.2; also elsewhere on the board

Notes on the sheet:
42NIBBLES FB4 FH-DO
WLAN Controller
IC14
Stecker vorbereitet für FT232-3V3 USB-Serial Adapter
I2C-Adapter 5V
I2C-Adapter 3V3
Port-Stecker für GPIO 5 und 3V3 Versorgung

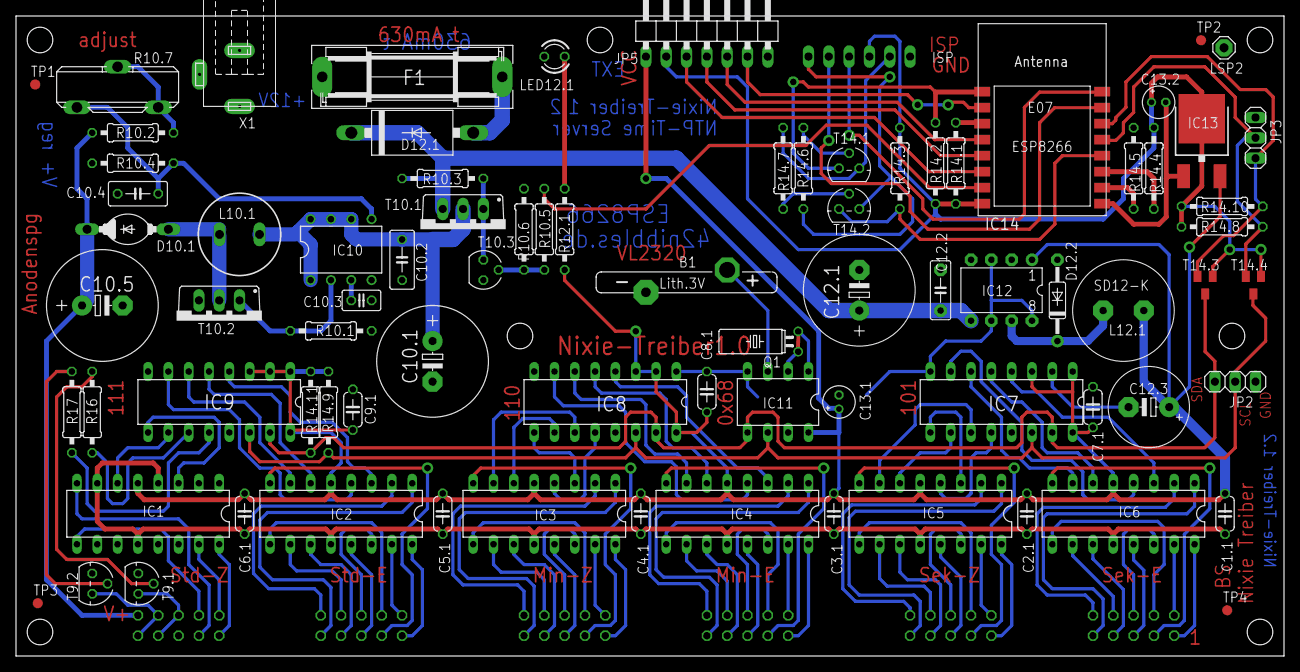
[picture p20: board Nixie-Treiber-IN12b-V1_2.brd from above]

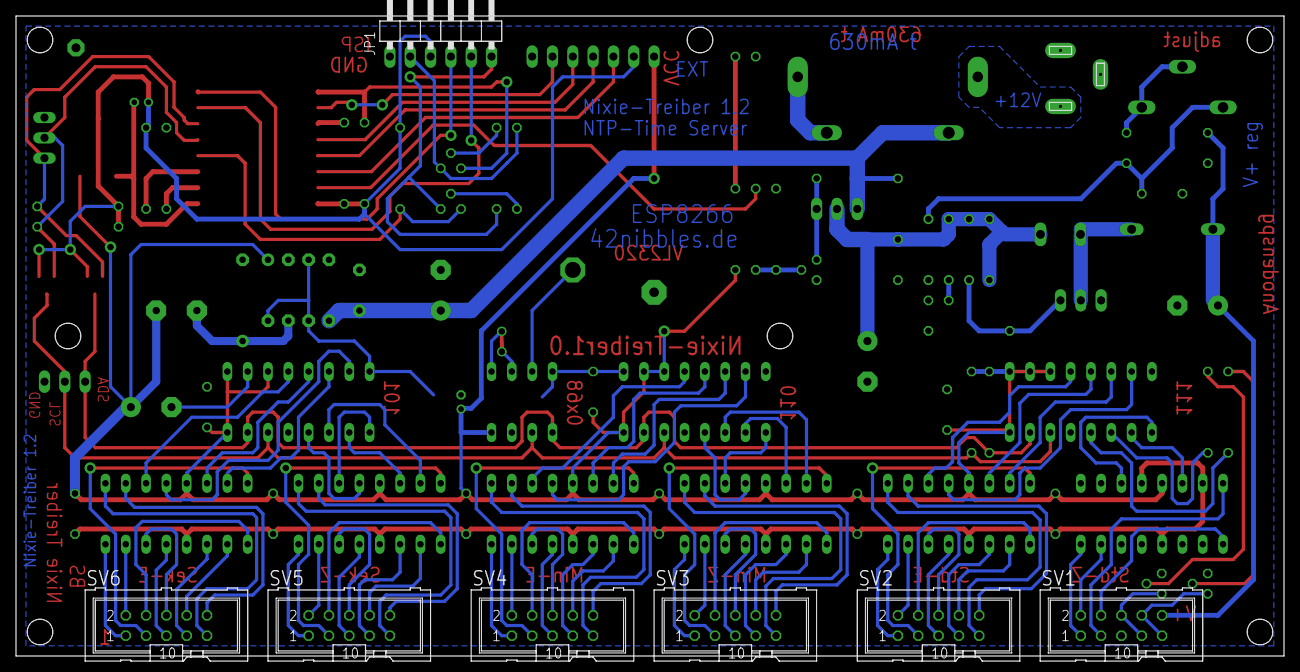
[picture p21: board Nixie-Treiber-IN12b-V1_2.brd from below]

Board: 2 copper layers, 158.5 x 80.0 mm, 88 parts (7 on the bottom side), 122 nets.

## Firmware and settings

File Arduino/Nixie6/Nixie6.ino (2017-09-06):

#include "Arduino.h"

//RTC relevant stuff
#include <DS1307RTC.h>
#include <Time.h>
#include <TimeLib.h>
#include <Timezone.h>
#include <Wire.h>

//(ESP) WiFi include stuff
#include <ESP8266WiFi.h>
#include <ESP8266WiFiAP.h>
#include <ESP8266WiFiGeneric.h>
#include <ESP8266WiFiMulti.h>
#include <ESP8266WiFiScan.h>
#include <ESP8266WiFiSTA.h>
#include <ESP8266WiFiType.h>
#include <WiFiClient.h>
#include <WiFiClientSecure.h>
#include <WiFiServer.h>
#include <WiFiUdp.h>

//Local class includes
#include <NixieClock.h>

//Local function prototypes
static time_t getNixieTime(void);
static time_t getNtpTime(void);
static time_t getRtcTime(void);
static bool wifi_setup(void);
static void print_wifi_mac_address(void);
static void print_wifi_status(void);

//WiFiManager
WiFiManager _wifimanager;
//Login for OTA Update option, (already entered login is saved)
const char *ota_user = "admin";
const char *ota_pass = "admin";
char resChar = n; 

//UDP
static WiFiUDP _udp;
static const unsigned int UDP_LOCAL_PORT = 2390; //local port to listen for UDP packets

//NTP stuff
//static constexpr char NTP_SERVER_NAME_S[] = "ntp2.ptb.de";
static constexpr char NTP_SERVER_NAME_S[] = "ntp1.t-online.de";

//We will use Central European Time (Frankfurt, Paris) as local time zone
TimeChangeRule CEST = {"CEST", Last, Sun, Mar, 2, 120}; //Central European Summer Time
TimeChangeRule CET = {"CET ", Last, Sun, Oct, 3, 60};   //Central European Standard Time
Timezone CE(CEST, CET);

//Nixie hardware stuff
static NixieClock _clock;
//TODO: Adjust twi settings to your mcu module here
//ESP8266-07 has swapped GPIO4/GPIO5 pins!
static constexpr uint8_t MY_SDA = 5;
static constexpr uint8_t MY_SCL = 4;

//The setup function is called once at startup of the sketch
void setup()
{
  //Serial setup
  Serial.begin(9600);
  while (!Serial)
    ; //wait for serial
  Serial.println("");
  Serial.println("Nixie Clock - Ver. 1.0 on Generic ESP8266 module");

  //TWI setup
  Wire.begin(MY_SDA,MY_SCL);
  Serial.print("MCU I2C pins configured to SDA on "); Serial.print(MY_SDA);
  Serial.print(", SCL on "); Serial.println(MY_SCL);

  //TODO: Adjust settings to your port expander hardware here
  //Pay attention to the usage of NixieClock::init().
  const uint8_t PCF8574_TWI_TYPE[3] = {0x27, 0x26, 0x25};
  //const uint8_t PCF8574A_TWI_TYPE[3] = {0x3f, 0x3e, 0x3d};
  _clock.begin(PCF8574_TWI_TYPE, true, true);
  //**** STOP ****


  /* Is handled by WifiManager
  // Try to start wifi interface
  if ( (wifi_setup() == true) && (_udp.begin(UDP_LOCAL_PORT) == true) ) {
    Serial.print("Created UDP local port ");
    Serial.println(_udp.localPort());
  }
*/
_wifimanager.setOtaUser(ota_user, ota_pass); 
if(_wifimanager.autoConnect("NixieClock")==false){ //TODO Add Backup method by failue 
  Serial.println("Problem with WifiManager init");
  return 0;
}

if(_udp.begin(UDP_LOCAL_PORT)==true){
  Serial.print("Created UDP local port ");
  Serial.println(_udp.localPort());
}

  // Try to start time syncing mechanisms
  Serial.println("Using localtime zone 'Berlin', CEST, CET");
  setSyncProvider( &getNixieTime ); // Arduino lib will care
}

// The loop function is called in an endless loop
void loop()
{
  static time_t old_time_utc = now();

  //Trigger this block each second
  if ( old_time_utc != now() ) {
    old_time_utc = now();
    //Local time output
    TimeChangeRule *tcr = nullptr;
    time_t local_time = CE.toLocal(old_time_utc, &tcr);
    int local_sec = second(local_time);
    if (local_sec >= 0 && local_sec < 56) {
      _clock.update(NixieClock::HMS, local_time);
    }
    else {
      _clock.update(NixieClock::dmy, local_time);
    }
  }
  uart_debug();
}

// **********************************************
// Local function declarations
// **********************************************
static time_t getNixieTime(void)
{
  static bool is_online;
  time_t utc_time = 0;

  if ( is_online ) {
    utc_time = getNtpTime();
    if ( utc_time != 0 )
      RTC.set(utc_time);
    else
      utc_time = getRtcTime();
  }
  else {
  //First round: Clock start-up
    //Accessing onboard real time clock must always be possible.
    utc_time = getRtcTime();
    if ( utc_time != 0 ) {
      is_online = true;
      setTime(utc_time);
    }
    else {
      // Bus error: Awaiting the watchdog timer biting us soon :-)
      while (1)
        ;
      // Never reached...
    }
    //Try to get ntp time over wifi
    utc_time = getNtpTime();
    if ( utc_time != 0 ) {
      setTime(utc_time);
      RTC.set(utc_time);
    }
  }
  return utc_time;
}

static time_t getNtpTime(void)
{
  //TODO: This is ugly and causes delays greater than necessary.
  if ( _udp.localPort() == 0 )
    return 0;

  while (_udp.parsePacket())
    ; //discard any previously received packets

  // Request ntp server ip address
  IPAddress time_server_ip;
  WiFi.hostByName(NTP_SERVER_NAME_S, time_server_ip);
  Serial.print("Requesting network time from ");
  Serial.print(NTP_SERVER_NAME_S);
  Serial.print(" (");
  Serial.print(time_server_ip);
  Serial.println(")");

  // Doing the NTP request
  const int NTP_PACKET_SIZE = 48;
  byte packet_buffer[NTP_PACKET_SIZE];
  memset(packet_buffer, 0, NTP_PACKET_SIZE);
  packet_buffer[0] = 0b11100011;  // LI, Version, Mode
  packet_buffer[1] = 0;     // Stratum, or type of clock
  packet_buffer[2] = 6;     // Polling Interval
  packet_buffer[3] = 0xec;  // Peer Clock Precision
  // 8 bytes of zero for Root Delay & Root Dispersion
  packet_buffer[12] = 49;
  packet_buffer[13] = 0x4e;
  packet_buffer[14] = 49;
  packet_buffer[15] = 52;
  // timestamp request
  _udp.beginPacket(time_server_ip, 123); // NTP server port is 123
  _udp.write(packet_buffer, NTP_PACKET_SIZE);
  _udp.endPacket();

  // Handling of NTP reply
  Serial.print("NTP reply");
  delay(1000);
  int rply_size = _udp.parsePacket();
  if ( rply_size ) {
    Serial.println("\t\t\t[OK]");
    _udp.read(packet_buffer, NTP_PACKET_SIZE);
    //the timestamp starts at byte 40 and is two words long
    unsigned long hword = word(packet_buffer[40], packet_buffer[41]);
    unsigned long lword = word(packet_buffer[42], packet_buffer[43]);
    unsigned long secs_since_1900 = hword << 16 | lword;
    // Unix time starts on Jan 1 1970. In seconds, that's 2208988800. So
    // we have to subtract seventy years.
    time_t unix_time = secs_since_1900 - 2208988800UL;
    return unix_time;
  }
  else {
    Serial.println("\t\t\t[FAILED]");
    return 0;
  }
}

static time_t getRtcTime(void)
{
  static bool rtc_connected;
  time_t utc_time = RTC.get();

  if ( rtc_connected && (utc_time != 0) ) {
    // Everything is online and fine
    return utc_time;
  }
  else {
    // First run should print some information.
    if ( utc_time != 0 ) {
      // It works.  Print boot messages.
      rtc_connected = true;
        //
      Serial.println("DS1307 real time clock found on I2C");
      Serial.print("UTC date is: ");
      Serial.print(day(utc_time));
      Serial.print(".");
      Serial.print(month(utc_time));
      Serial.print(".");
      Serial.println(year(utc_time));
      Serial.print("UTC time is: ");
      Serial.print(hour(utc_time));
      Serial.print(":");
      Serial.print(minute(utc_time));
      Serial.print(":");
      Serial.println(second(utc_time));
    }
    else {
      if ( RTC.chipPresent() ) {
        // A chip is present, but it was not initialized.
        rtc_connected = true;
        Serial.println("Found unitialized DS1307 real time clock");
        Serial.println("Setting rtc time temporary to 1 January 1970");
        RTC.set(0);
        utc_time = 1;
      }
      else {
        rtc_connected = false;
        Serial.println("");
        Serial.println("Severe hardware failure");
        Serial.println("Accessing DS1307 real time clock failed");
        Serial.println("");
      }
    }
  }
  return utc_time;
}

static void print_wifi_mac_address(void)
{
  uint8_t mac[6];
  WiFi.macAddress(mac);
  Serial.print("MAC: ");
  Serial.print(mac[0], HEX);
  Serial.print(":");
  Serial.print(mac[1], HEX);
  Serial.print(":");
  Serial.print(mac[2], HEX);
  Serial.print(":");
  Serial.print(mac[3], HEX);
  Serial.print(":");
  Serial.print(mac[4], HEX);
  Serial.print(":");
  Serial.println(mac[5], HEX);
}

static void print_wifi_status(void)
{
  Serial.print("WiFi status: ");
  switch (WiFi.status()) {
  case WL_CONNECTED:
    Serial.println("WL_CONNECTED");
    break;
  case WL_NO_SHIELD:
    Serial.println("WL_NO_SHIELD");
    break;
  case WL_IDLE_STATUS:
    Serial.println("WL_IDLE_STATUS");
    break;
  case WL_NO_SSID_AVAIL:
    Serial.println("WL_NO_SSID_AVAIL");
    break;
  case WL_SCAN_COMPLETED:
    Serial.println("WL_SCAN_COMPLETED");
    break;
  case WL_CONNECT_FAILED:
    Serial.println("WL_CONNECT_FAILED");
    break;
  case WL_CONNECTION_LOST:
    Serial.println("WL_CONNECTION_LOST");
    break;
  case WL_DISCONNECTED:
    Serial.println("WL_DISCONNECTED");
    break;
  default:
    Serial.println("Unknown");
    break;
  }
}

static void uart_debug(void){
  //Easy UART Debug interface
    if (resChar = Serial.read())
    {
      switch (resChar)
      {
      //Reset saved station logins
      case 'r':
        resChar = 'n';
        wifimanager.resetSettings();
        wifimanager.autoConnect("Pixie Uhr");
        break;
      //Restart ESP
      case 'p':
        resChar = 'n';
        ESP.restart();
        break;
      }
    }
  }

/* Is handled in WifiManager
static bool wifi_setup(void)
{
  const int WIFI_TIMEOUT_SECS = 16;
  bool wifi_available = true;

  //Connecting to WiFi
  Serial.print("WiFi connecting to SSID: ");
  Serial.println(_SSID);
  print_wifi_mac_address();
  //
  WiFi.disconnect();
  WiFi.mode(WIFI_AP_STA);
  WiFi.begin(_SSID, _PASS);
  time_t connection_moment = now();
  while (WiFi.status() != WL_CONNECTED) {
    delay(500);
    Serial.print(".");
    if ( (connection_moment + WIFI_TIMEOUT_SECS) <= now() ) {
      // Timeout reached
      wifi_available = false;
      Serial.println("\t\t[FAILED]");
      break;
    }
  }
  if ( wifi_available ) {
    // Print some boot messages
    Serial.println("\t\t\t[OK]");
    Serial.print("IP address: ");
    Serial.println(WiFi.localIP());
    print_wifi_status();
  }
  return wifi_available;
}
*/

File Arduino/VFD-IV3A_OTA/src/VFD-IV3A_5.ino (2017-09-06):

/*
ESP8266 : NTP Time + Timezone
Created 07 May 2016 by Ralf Bohnen - www.Arduinoclub.de
This example code is in the public domain.
*/

//(ESP) WiFi include stuff
#include <ESP8266WiFi.h>
#include <ESP8266WiFiAP.h>
#include <ESP8266WiFiGeneric.h>
#include <ESP8266WiFiMulti.h>
#include <ESP8266WiFiScan.h>
#include <ESP8266WiFiSTA.h>
#include <ESP8266WiFiType.h>
#include <WiFiClient.h>
#include <WiFiClientSecure.h>
#include <WiFiServer.h>
#include <WiFiUdp.h>

// RTC  Stuff ###################################################################
#include <DS1307RTC.h>
#include <Time.h>
#include <Wire.h>
#include <TimeLib.h>  //by Paul Stoffregen, not included in the Arduino IDE !!!
#include <Timezone.h> //by Jack Christensen, not included in the Arduino IDE !!!

// Shift Register HV5812 and Ports #############################################
#include "HV5812.h"
#include "multiplexer.h"

// OTA Stuff ###################################################################
// WifiManager + OTA https://github.com/FacepalmMute/WiFiManager
#include <WiFiManager.h>

// Port Pins are defined in HV5812.h ##########################################

uint8_t fieldMux[6]; // field to display

int segmentIndex = 14;

unsigned long previousMillis = 0;
//const long interval = 1000;
volatile bool wasConnected = false;

bool isConnected(long timeOutSec)
{
  timeOutSec = timeOutSec * 1000;
  int z = 0;
  while (WiFi.status() != WL_CONNECTED)
  {
    delay(200);
    Serial.print(".");
    if (z == timeOutSec / 200)
    {
      return false;
    }
    z++;
  }
  return true;
}

//### NTP, TIME & TIMEZONE ###################################################################

//WiFiManager
WiFiManager wifimanager;
//Login for OTA Update option, (already entered login is saved)
const char *ota_user = "admin";
const char *ota_pass = "admin";
char resChar = n; //char for uart communication

//UDP
WiFiUDP Udp;
unsigned int localPort = 123;

//NTP Server
char ntpServerName1[] = "ntp1.t-online.de";
char ntpServerName2[] = "ntp2.ptb.de";

//Timezone
//Central European Time (Frankfurt, Paris)
TimeChangeRule CEST = {"CEST", Last, Sun, Mar, 2, 120}; //Central European Summer Time
TimeChangeRule CET = {"CET ", Last, Sun, Oct, 3, 60};   //Central European Standard Time
Timezone CE(CEST, CET);
TimeChangeRule *tcr; //pointer to the time change rule, use to get the TZ abbrev
time_t utc, local;

const int NTP_PACKET_SIZE = 48;     // NTP time is in the first 48 bytes of message
byte packetBuffer[NTP_PACKET_SIZE]; //buffer to hold incoming & outgoing packets

bool getNtpTime(char *ntpServerName)
{
  //	Serial.print(F("NTP request..."));
  if (timeStatus() == timeSet)
  {
    //		Serial.println(F("not necessary"));
    return true;
  }

  IPAddress ntpServerIP; // NTP server's ip address

  while (Udp.parsePacket() > 0)
    ; // discard any previously received packets
  Serial.println(F("Transmit NTP Request"));
  // get a random server from the pool
  WiFi.hostByName(ntpServerName, ntpServerIP);
  Serial.print(ntpServerName);
  Serial.print(": ");
  Serial.println(ntpServerIP);
  sendNTPpacket(ntpServerIP);
  uint32_t beginWait = millis();
  while (millis() - beginWait < 1500)
  {
    int size = Udp.parsePacket();
    if (size >= NTP_PACKET_SIZE)
    {
      Serial.println(F("Receive NTP Response"));
      if (!Udp.read(packetBuffer, NTP_PACKET_SIZE))
        Serial.printf("ERROR in Udp.read"); // read packet into the buffer
      unsigned long secsSince1900;
      // convert four bytes starting at location 40 to a long integer
      secsSince1900 = (unsigned long)packetBuffer[40] << 24;
      secsSince1900 |= (unsigned long)packetBuffer[41] << 16;
      secsSince1900 |= (unsigned long)packetBuffer[42] << 8;
      secsSince1900 |= (unsigned long)packetBuffer[43];
      setTime(secsSince1900 - 2208988800UL);
      //setTime(23, 55, 0, 30, 3, 2016); //simulate time for test
      return true;
    }
  }
  Serial.println(F("FATAL ERROR : No NTP Response."));
  return false; // return 0 if unable to get the time
}

// send an NTP request to the time server at the given address
void sendNTPpacket(IPAddress &address)
{
  // set all bytes in the buffer to 0
  memset(packetBuffer, 0, NTP_PACKET_SIZE);
  // Initialize values needed to form NTP request
  // (see URL above for details on the packets)
  packetBuffer[0] = 0b11100011; // LI, Version, Mode
  packetBuffer[1] = 0;          // Stratum, or type of clock
  packetBuffer[2] = 6;          // Polling Interval
  packetBuffer[3] = 0xEC;       // Peer Clock Precision
                                // 8 bytes of zero for Root Delay & Root Dispersion
  packetBuffer[12] = 49;
  packetBuffer[13] = 0x4E;
  packetBuffer[14] = 49;
  packetBuffer[15] = 52;
  // all NTP fields have been given values, now
  // you can send a packet requesting a timestamp:
  Udp.beginPacket(address, 123); //NTP requests are to port 123
  Udp.write(packetBuffer, NTP_PACKET_SIZE);
  Udp.endPacket();
}

static void print_wifi_mac_address()
{
  uint8_t mac[6];
  WiFi.macAddress(mac);
  Serial.print("MAC: ");
  Serial.print(mac[0], HEX);
  Serial.print(":");
  Serial.print(mac[1], HEX);
  Serial.print(":");
  Serial.print(mac[2], HEX);
  Serial.print(":");
  Serial.print(mac[3], HEX);
  Serial.print(":");
  Serial.print(mac[4], HEX);
  Serial.print(":");
  Serial.println(mac[5], HEX);
}
//### TIME Printing only  on demand ###################################################################

void printTime(time_t t)
{
  sPrintI00(hour(t));
  sPrintDigits(minute(t));
  sPrintDigits(second(t));
  Serial.print(' ');
  Serial.print(dayShortStr(weekday(t)));
  Serial.print(' ');
  sPrintI00(day(t));
  Serial.print(' ');
  Serial.print(monthShortStr(month(t)));
  Serial.print(' ');
  Serial.print(year(t));
  Serial.println(' ');
}

//Print an integer in "00" format (with leading zero).
//Input value assumed to be between 0 and 99.
void sPrintI00(int val)
{
  if (val < 10)
    Serial.print('0');
  Serial.print(val, DEC);
  return;
}

//Print an integer in ":00" format (with leading zero).
//Input value assumed to be between 0 and 99.
void sPrintDigits(int val)
{
  Serial.print(':');
  if (val < 10)
    Serial.print('0');
  Serial.print(val, DEC);
}
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

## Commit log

2017-04-05 Hardware description added.
    [Nixie-Treiber_1_0.brd, Nixie-Treiber_1_0.sch, Nixie4_IN-1A_1_0.sch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]
2017-08-14 Hardware description updated.
    [Nixie-Treiber-IN12b-V1_2.brd, Nixie-Treiber-IN12b-V1_2.sch, Nixie6_IN-12A_1_0.sch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]
2017-09-06 Add WifiManager + OTA to current file structure (UNTESTED)
2017-09-30 First Build fixes. (Nixie6)
    [Nixie6.ino]
